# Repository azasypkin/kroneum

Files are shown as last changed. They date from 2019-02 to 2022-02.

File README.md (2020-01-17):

# 🕐 Kroneum



**Disclaimer:** I needed a dumb, autonomous, configurable and GUI-less physical timer to better manage my own time during the day and that is how Kroneum was born. 
Another goal was to see how well Rust fits into embedded development (basic interactions with MCU, USB stack and I2C driver).

------------------------

**Kroneum** is an experimental, accessible (no GUI) and fully open source (both in code and hardware) time tracker device.

There is neither GUI/LCD nor Wi-Fi/Bluetooth interface available, just two buttons one can use to configure the timer. More advanced users can use built-in USB functionality
to configure device (via dedicated [CLI tool](./sw/cli) with optional Web interface), upgrade firmware (via [DFU interface](./sw/firmware/README.md)) or upload various Krouneum "recipes" (e.g. to repurpose device completely).

## Usage

By default device stays in a standby low power mode and wakes up as soon as any of the button is being pressed for 3-5 seconds. As mentioned above there are just two buttons: **Ⅰ** (Roman `one`) and **Ⅹ** (Roman `ten`).

* Long press on **Ⅰ** or **Ⅹ** button when in `StandBy` mode - device enters into `Setup` mode
* Short press on **Ⅰ** when in `Setup` mode - increases desired timer by one `unit`
* Short press on **Ⅹ** when in `Setup` mode - increases desired timer by ten `units`
* Long press on **Ⅰ** when in `Setup` mode - sets timer treating `unit` as a `second` (see example below)
* Long press on **Ⅹ** when in `Setup` mode - sets timer treating `unit` as a `minute` (see example below)
* Long press on both **Ⅰ** *and* **Ⅹ** when in `Setup` mode - sets timer treating `unit` as an `hour` (see example below)
* Long press on **Ⅰ** *or* **Ⅹ** when in `Alarm` mode - resets current alarm if any and enters `Setup` mode
* Long press on both **Ⅰ** *and* **Ⅹ** when in `Alarm` mode - resets current alarm if any and enters `StandBy` mode
* **Very** long press (5 seconds) on both **Ⅰ** *and* **Ⅹ** - enters `Configuration` mode and powers up USB interface

Once timer fires up it will be repeated every 10 seconds (configurable) until it's acknowledged by the long press on both **Ⅰ** *and* **Ⅹ**.

## Examples:

* Long Press on **Ⅰ** + 5 short presses on **Ⅰ** + long press on **Ⅰ** = `5s` timer
* Long Press on **Ⅰ** + 5 short presses on **Ⅰ** + long press on **Ⅹ** = `5m` timer
* Long Press on **Ⅰ** + 5 short presses on **Ⅰ** + long press on both **Ⅰ** *and* **Ⅹ** = `5h` timer
* Long Press on **Ⅰ** + 1 short press on **Ⅰ** + 2 short presses on *Ⅹ** + long press on **Ⅰ** = `21s` timer
* Long Press on **Ⅰ** + 1 short press on **Ⅹ** + long press on **Ⅹ** = `10m` timer
* and so on

## Configuration

Advanced users can configure device via USB with the help of dedicated [CLI tool](./sw/cli), assuming device is in `Configuration` mode and
connected to the host PC via micro USB cable:

```bash
$ cargo run -- info

$ cargo run -- beep -n5

$ cargo run -- alarm get
$ cargo run -- alarm set "5m 15s"

$ cargo run -- flash read 0x1f
$ cargo run -- flash write 0x1f 10
$ cargo run -- flash erase

$ cargo run -- reset

```

It's also possible to use CLI tool as a standalone server with a minimalistic Web interface:

```bash
$ cargo run -- ui
  Running Kroneum Web UI on http://127.0.0.1:8080
``` 

Web server is bound to a local `http://127.0.0.1:8080` address and can be accessed with any modern browser:

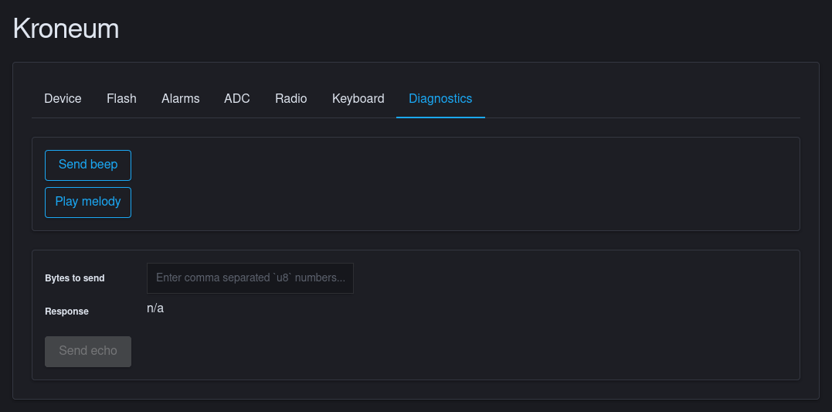
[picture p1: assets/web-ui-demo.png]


Run `cargo run -- help` for more details.

**NOTE:** To use CLI tool without `root` privilege you may need to add the following `udev` rule:
```
/etc/udev/rules.d/50-kroneum.rules
----------
SUBSYSTEMS=="usb", ATTRS{idVendor}=="1209", ATTRS{idProduct}=="deed", GROUP="users", MODE="0660"
```

And then manually force `udev` to trigger this rule:
```bash
# udevadm trigger
```

In the future releases Web interface will be using [WebHID API](https://wicg.github.io/webhid/) completely eliminating the need in
the local Web server.

## Building custom firmware

If you feel adventurous you can easily build and flash custom firmware to Kroneum. You can use `./scripts/flash.sh` script 
from [fw](./sw/firmware) folder to build and flash default firmware or few custom [examples](./sw/firmware/bin/examples):

Default firmware:
```bash
# Default firmware
$ ./scripts/flash.sh 

# Example: blinking through TP1/SDA pad exposed on the back side of Kroneum PCB
$ ./scripts/flash.sh blinky

# Example: interfacing with SSD1306 LCD via TP1/SDA and TP2/SCL pads exposed on the back side of Kroneum PCB
$ ./scripts/flash.sh i2c_ssd1306 
``` 

The `flash.sh` script is essentially consequent calls of `cargo build --release ...`, `cargo objcopy --release ...` and `dfu-util ...`.

## Prototype or DIY

Schematics is done in `KiCad` and can be found [here](./hw/pcb/Rev_0.5). PCB includes SWD, I2C and CR2032 connectors and may look a bit
oversized because of that, but on the bright side hand soldering and [CNC engraving](./hw/pcb/Rev_0.3/cnc) was a breeze.

The most recent enclosure was machined from 5mm (base and cap) and 2mm (buttons) Delrin and the older versions were machined from
5mm Plexiglas (walls and buttons) and 2mm Delrin (base and cap). G-Code can be found [here](./hw/enclosure/Rev_0.5/cnc).

See [PCB](./hw/pcb/Rev_0.6/demo) and [enclosure](./hw/enclosure/Rev_0.6/demo) renders and photos of how it turned in real:

#### Demo PCB and enclosure (rendered vs real)
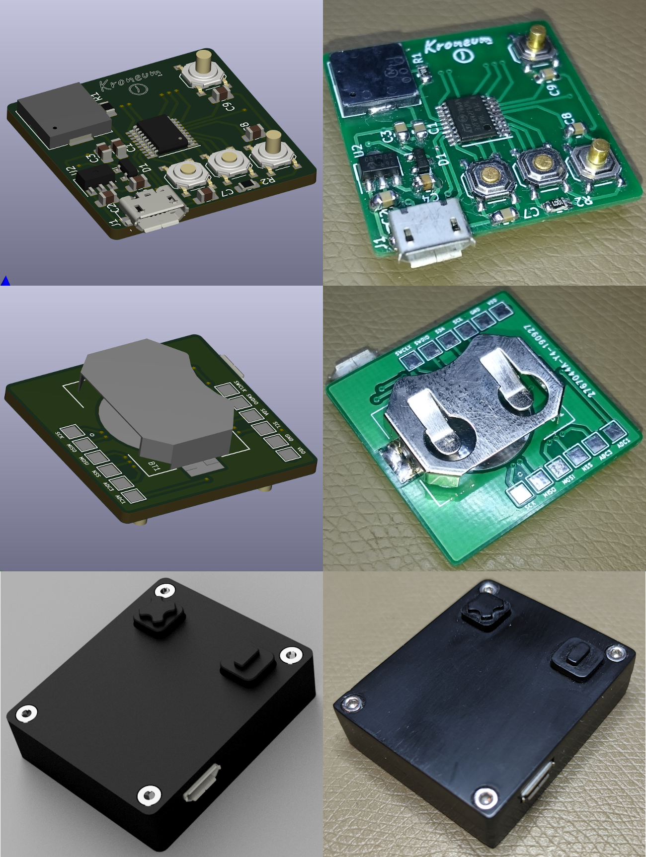
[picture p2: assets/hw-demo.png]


<details>
  <summary><b>Older versions</b></summary>
 
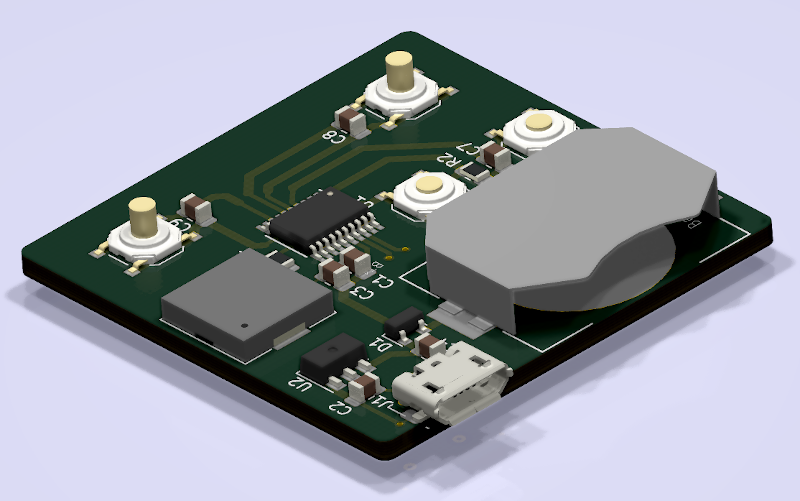
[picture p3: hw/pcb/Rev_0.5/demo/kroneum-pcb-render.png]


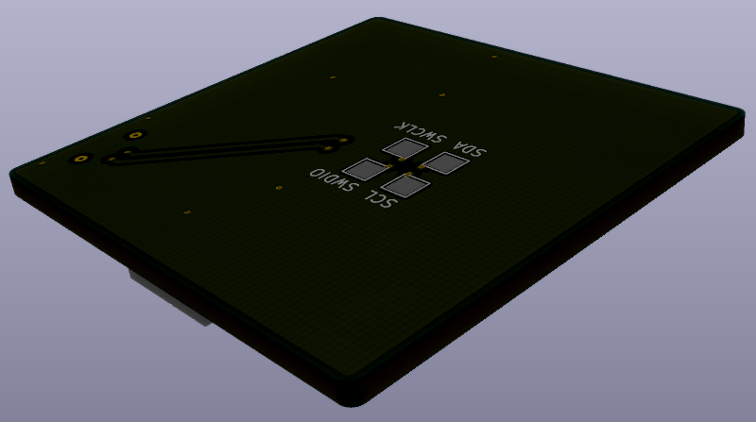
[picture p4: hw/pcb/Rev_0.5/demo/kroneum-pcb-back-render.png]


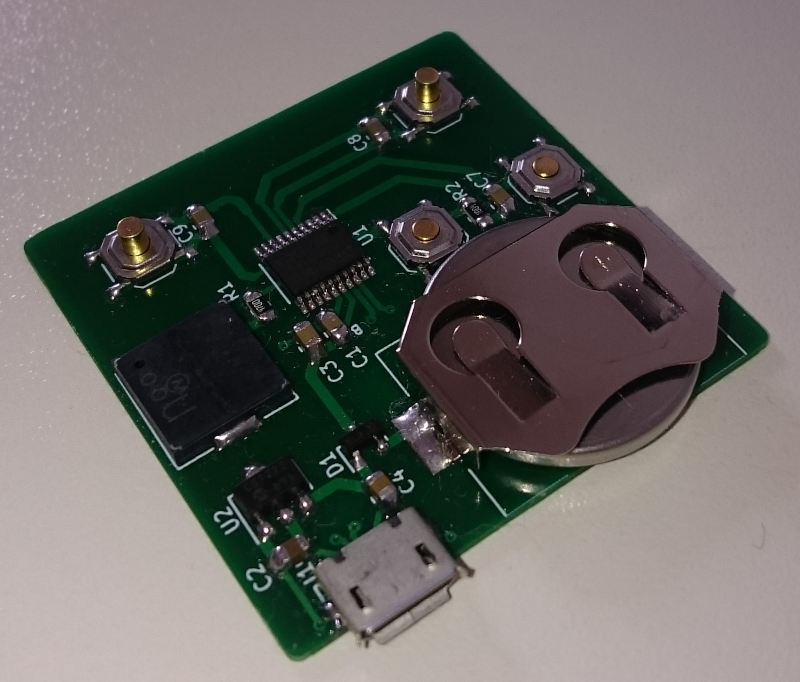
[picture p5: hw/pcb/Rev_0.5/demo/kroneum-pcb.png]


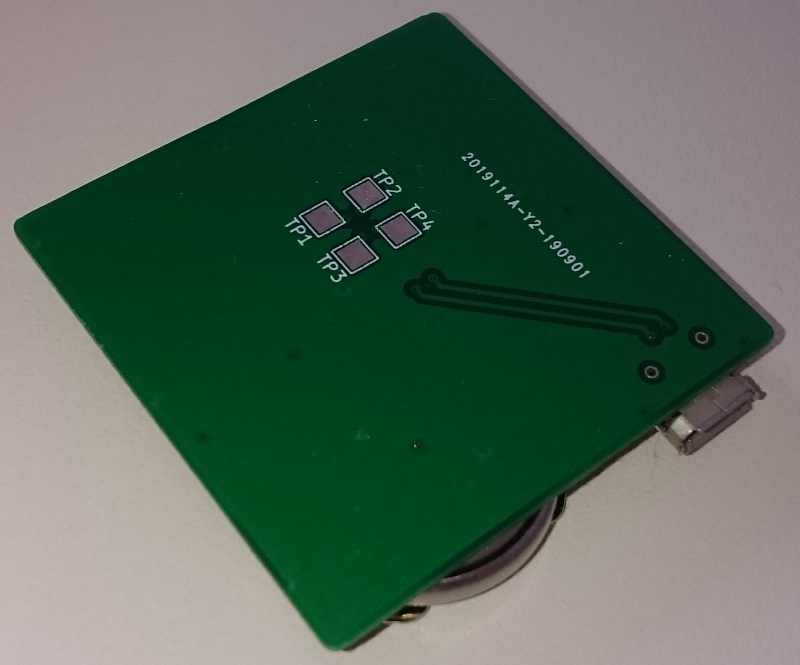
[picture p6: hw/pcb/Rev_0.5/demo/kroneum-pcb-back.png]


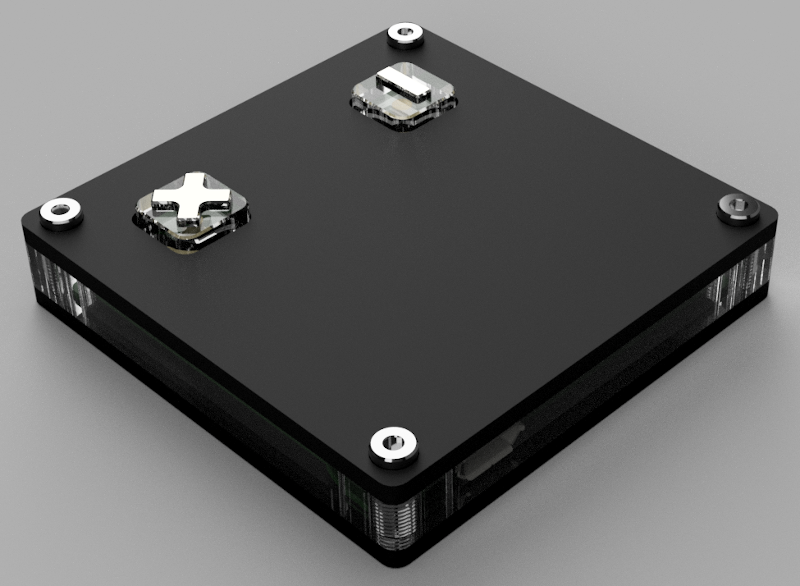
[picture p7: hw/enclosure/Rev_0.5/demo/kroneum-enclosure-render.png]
enclosure


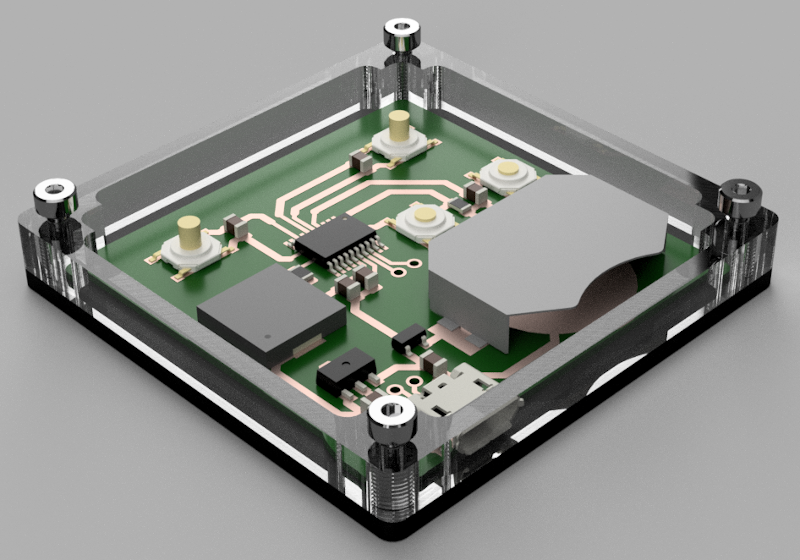
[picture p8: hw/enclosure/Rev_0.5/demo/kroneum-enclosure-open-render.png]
enclosure


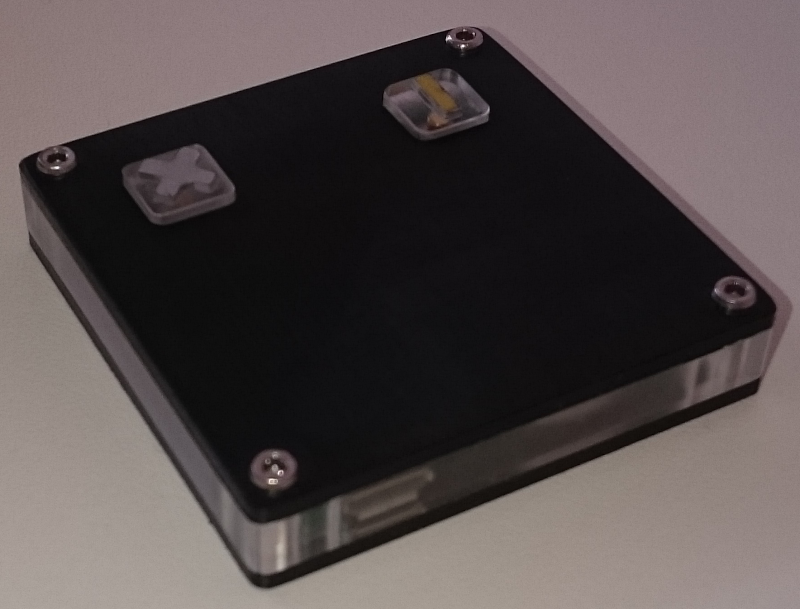
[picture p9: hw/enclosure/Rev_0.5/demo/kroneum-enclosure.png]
enclosure


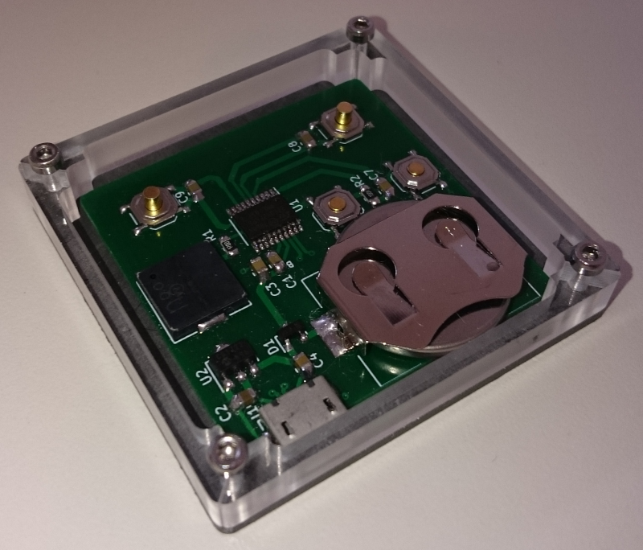
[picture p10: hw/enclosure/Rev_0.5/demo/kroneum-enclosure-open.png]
enclosure


</details>

-.- .-. --- -. . ..- --

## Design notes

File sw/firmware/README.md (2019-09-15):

## Debugging

Firs of all read [The Embedded Rust Book/Hardware](https://rust-embedded.github.io/book/start/hardware.html)!

Will debug with the help of ST-Link included into `STM32F0DISCOVERY` evaluation board. To program and debug `stm32f042f4p6` 
with this board remove the 2 jumpers from CN2 (see [en.DM00050135.pdf](./docs/en.DM00050135.pdf), page 16):

| `STM32F0DISCOVERY` CN3/SWD connector | `STM32F042F4P6` |
| --- | ---:|
| 1 - VDD_TARGET - VDD from target MCU | 16 - VDD __and__ 5 - VDDA |
| 2 - SWCLK - SWD clock | 20 - PA14 |
| 3 - GND - Ground | 15 - GND |
| 4 - SWDIO - SWD data input/output | 19 - PA13 |
| 5 - NRST - RESET of target MCU | 4 - NRST |
| 6 - SWO - Reserved | NC |

1. Add `udev` rule for the `STMicroelectronics ST-LINK/V2`:

```bash
$ sudo vim /etc/udev/rules.d/99-stlink.rules

-------
ATTRS{idVendor}=="0483", ATTRS{idProduct}=="3748", MODE="0666"
-------

$ sudo udevadm trigger
```

1. Build project with one of the following commands:
```bash
$ cargo build
$ cargo build --target=thumbv6m-none-eabi
$ cargo build --target=thumbv6m-none-eabi --release
$ cargo +nightly build --target=thumbv6m-none-eabi --release --features nightly
```
2. Run `openocd -f openocd.cfg`
3. In another terminal run `arm-none-eabi-gdb  -x openocd.gdb target/thumbv6m-none-eabi/release/kroneum-bin`

# Firmware Upload via USB DFU

| `Micro USB` | `STM32F042F4P6`        |
| ------------------------------------:|
| 1 - VBUS +  | NC                     |
| 2 - DATA -  | 09 - PA11 - USB DM     |
| 3 - DATA +  | 10 - PA12 - USB DP     |
| 4 - ID      | NC                     |
| 5 - GND     | 15 - GND               |

Pin 1 (PB8-BOOT0) should be connected to VDD\VDDA (+3.3V).

Also make sure you read documentation for [cargo-binutils](https://github.com/rust-embedded/cargo-binutils) and [dfu-util](http://dfu-util.sourceforge.net/dfuse.html).

1. Build binary with:
```bash
$ cargo build --release -p kroneum-bin
$ $(find $(rustc --print sysroot) -name llvm-objcopy) ./target/thumbv6m-none-eabi/release/kroneum-bin -O binary ./target/fw-upload.bin
Or call the following command from the `./bin` subfolder
$ cargo objcopy --bin kroneum-bin --release -- -O binary ../target/fw-upload.bin
```

2. Upload binary with:
```bash
$ dfu-util -a 0 -d 0483:df11 -s 0x08000000:leave -D ./target/fw-upload.bin
```

3. Backup binary with:
```bash
$ dfu-util -U fw-from-device.bin -a 0 -d 0483:df11
``` 

## Notes

1. Steps 1-3 above can be replaced with just `$ ./scripts/flash.sh`.

2. If binary is too large GDB may fail so try to use `--release` flag with `cargo build`.

3. To reload program on the MCU use `monitor reset halt`

4. RTC & Low Power modes: https://github.com/mattico/stm32f0-Discovery_Tools/blob/master/ST_Example_Projects/Projects/Peripheral_Examples/PWR_CurrentConsumption/stm32f0xx_lp_modes.c

## Useful links

1. [The Embedded Rust Book](https://rust-embedded.github.io/book)
2. [Firmware for Anne Pro Keyboard written in Rust](https://github.com/ah-/anne-key)
3. [USB HID device development on STM32 F042](http://andybrown.me.uk/2016/01/09/f042usbhid/)
4. [A development board for the STM32F042 TSSOP package](http://andybrown.me.uk/2015/10/31/stm32f042dev/) and [schematics](http://andybrown.me.uk/wp-content/images/stm32f042dev/schematic.pdf)
5. [STM32F042 Breakout](http://ebrombaugh.studionebula.com/embedded/stm32f042breakout/index.html)
6. [Tim's Open Micro USB](https://github.com/im-tomu)
7. [Online Circuit Simulator](http://www.falstad.com/circuit/circuitjs.html?startCircuit=lrc.txt)
8. [ifUSB repo](https://github.com/julbouln/ifusb) and [USB multi protocol interface tool](https://hackaday.io/project/14864-ifusb)

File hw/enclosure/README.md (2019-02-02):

## Ideas

* Magnets in enclosure base and cap
* Inserts + screws like https://www.aliexpress.com/item/Uxcell-20pcs-M6-Threaded-Insert-Nuts-Interface-Hex-Socket-Wooden-Furniture-Accessories-Screws-Carbon-Steel-6/32922841586.html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,searchweb201602_4_10320_10065_10068_10547_319_10548_317_10696_453_10084_454_10083_433_10618_431_10304_10307_10820_10821_537_10302_536_5736111_5736011_10843_10059_10884_10887_100031_10319_321_322_10103,searchweb201603_59,ppcSwitch_0&algo_expid=8dacf359-6220-46c2-94f5-eb0ac2e569ab-5&algo_pvid=8dacf359-6220-46c2-94f5-eb0ac2e569ab&transAbTest=ae803_4
* Tight fit https://www.thingiverse.com/thing:1625233

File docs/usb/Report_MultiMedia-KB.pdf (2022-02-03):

## Enhanced Keyboard with Multimedia capability and Application Launch Function

Raj Parihar

Introduction

This application note explains the implementation of Universal Serial Bus (USB) keyboard with enhanced features using microchip‘s USB firmware. Firmware incorporates QWERTY keyboard, multimedia volume control, system power management functionalities along with Application Launch (AL) functions. Design has been implemented using Human Interface Device (HID) class in a composite USB device manner with consumer control application.

Features

- Simple keyboard with Alpha-Numeric keys
- Power management function support i.e. System Wake UP, SLEEP etc.
- Multimedia functionalities with Volume control
- Application Launch capability
- Compatible with Windows and Linux operating system
- No Custom Driver Required, uses generic drivers
- Firmware is portable across all PIC with USB part

USB Protocol: Overview

USB is a simple, reliable, and versatile interface. It is a cost effective and fast means of communication between devices and Host with many other advantages. Universal Bus connectors and 4-wire simple connection makes it a suitable interface for compact devices as well. The bus allows peripherals to be attached, configured, used and detached while the host and other peripherals are in operation.

Application Space in USB

According to USB 2.0 specification

Specification | Bit Rate | Typical Application
LOW - SPEED | 1.5 Mbps | Interactive Devices i.e. Keyboard, Mouse, joysticks etc.
FULL - SPEED | 12 Mbps | Phone, Audio i.e. Broadband, Microphone etc.
HIGH - SPEED | 480 Mbps | Video, Storage i.e. Video application, Imaging etc.

USB Device Terminology

USB device is a collection of end points which can be addressed from USB host controller uniquely. According to USB 2.0 specification Endpoint is ―a uniquely addressable portion of USB device that is the source or sink of information in a communication flow between the host and device‖. The unique address required for each endpoint consists of an endpoint number (which may range from 0 to 15) and direction (IN or OUT). The endpoint direction is always from the host‘s perspective; IN is towards the host and OUT is away from the host. An endpoint configured to do control transfers must transfer data in both directions, so a control endpoint actually consists of a pair of IN and OUT endpoints that share an endpoint number. All USB devices must have Endpoint 0 configured as a control endpoint.

USB Data Transfer Type

USB 2.0 supports four types of data transfers: Control, Bulk, Interrupt and Isochronous.
- Control transfer is used to configure a device at the time of plug-in and can be used for other device specific purposes, including control of other pipes on the device.
- Bulk data transfers are used when the data is generated or consumed in relatively large, bulky quantities.
- Interrupt data transfers are used for timely, and reliable, delivery of data. For example, characters or coordinates with human perceptible echo or feedback response characteristics.
- Isochronous data transfers occupy a pre-negotiated amount of USB bandwidth with pre-negotiated delivery latency (also called streaming real-time transfers).

Human Interface Device Class

The human interface device (HID) class was one of the first USB classes to be supported under Windows and other operating Systems. On PCs running Windows, applications can communicate with HID using the generic HID drivers built into the operating system such as kbdhid.sys and mouhid.sys.

The HID class consists of devices that are used by humans to control the operation of computer systems. Typical examples of HID class devices include:
- Keyboards and pointing devices—for example, standard mouse devices, trackballs, and joysticks.
- Front-panel controls—for example: knobs, switches, buttons, and sliders.
- Controls that might be found on devices such as telephones, VCR remote controls, games or simulation devices—for example: data gloves, throttles, steering wheels, and rudder pedals.

Microchip’s USB Solution

Microchip USB Firmware Framework can be used to create new USB applications. It can be thought of as a reference design project, containing the necessary firmware for USB operation and provides a placeholder for the user‘s code.

The USB Firmware Framework also provides a set of modular firmware interfaces that handle most of the work for implementing USB communications. Each firmware reference project is written to have a cooperative multitasking environment; thus, no blocking functions should be implemented in user code. The files are tightly interdependent, and pass information between themselves during compile time to create the complete USB configuration.

The PIC18 with USB peripheral device families contains a full-speed and low-speed compatible USB Serial Interface Engine (SIE) that allows fast communication between any USB host and PIC microcontroller. The SIE can be interfaced directly to the USB, utilizing the internal transceiver.

For complete information of functions and stack please refer PICDEM FS USB demo board‘s user guide and PIC18 Data sheet available on Microchip‘s website.

Overview: Design

For demonstration purpose a 4 by 4 keypad has been interfaced in current version. Any other type of keyboard with different numbers of rows and columns can be interfaced by writing the appropriate scanning routines for the same. The keypad works in two different modes as following.

Normal Mode:
In normal mode keypad works as simple keyboard. It sends alpha-numeric keys to host whenever a key is pressed. Pressing ‗F‘ (Select) sends the keypad in ―Multimedia Mode‖. Again pressing ‗F‘ brings keypad back in normal mode.

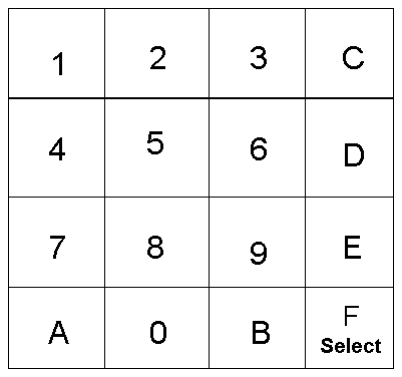
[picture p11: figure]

Figure: Alpha-Numeric Keyboard

Multi Media Mode:
In this mode keypad supports following types of tasks:
1. Volume Control (UP, DOWN and MUTE): [first 3 keys]
2. System Control (System SLEEP and WAKE UP): [ 2 keys towards RHS ]
3. AL function (Media player, Calculator, Browser, Email ): [3 keys in 3rd row
and 1st in 2nd row]
4. Browser Control (Forward, Backward, Refresh): [3 keys in last row]
5. launch ‗Search‘ and ‗Favorite‘: [ 2 keys in 2nd row]

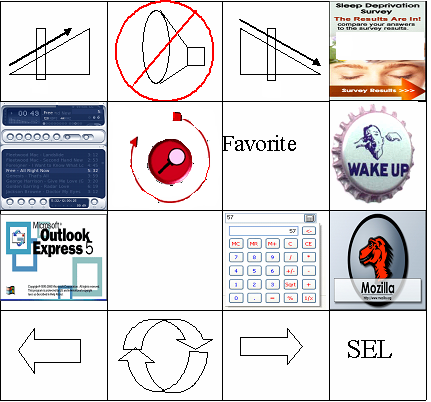
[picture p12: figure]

Figure: Multimedia functions

Implementation

In this implementation of USB/HID keyboards with enhanced features the following design guidelines have been followed.

1. Two HID interfaces has been implemented in a USB composite device fashion, where one interface is used for a standard QWERTY keyboard report that's identical to the keyboard boot protocol report, and the other interface is used for the new, enhanced functionality.
2. Second interface is a consumer control HID usage that implements Volume Up, Volume Down, Mute, and WWW Home buttons using Report ID 1.
3. Keyboard is equipped with Power Management buttons (Sleep, Wake-up, or Power Down buttons), which is implemented in Report ID 2 of second interface.

Interfaces and Endpoint Diagram

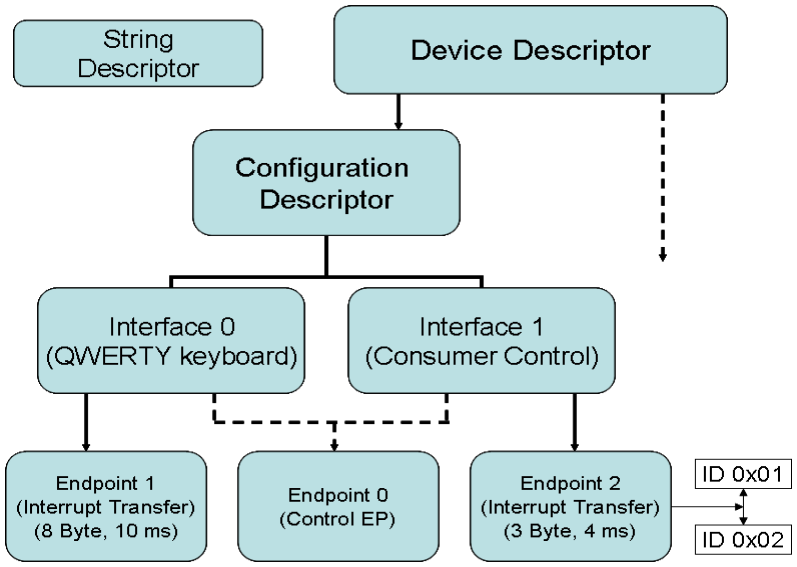
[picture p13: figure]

Figure: Available Endpoints and Interfaces in device

USB Descriptors

### 1. Device Descriptor:

Device descriptor is very first data structure which includes information such as what USB revision the device complies with, the Product and Vendor IDs used to load the appropriate drivers and the number of possible configurations the device can have

/* Device Descriptor */
rom USB_DEV_DSC device_dsc=
{
Sizeof (USB_DEV_DSC), | // Size of this descriptor in bytes: 18
DSC_DEV, | // DEVICE descriptor type: 01
0x0200, | // USB Spec Release Number in BCD format
0x00, | // Class Code; Defined in Interface DSC
0x00, | // Subclass code
0x00, | // Protocol code
EP0_BUFF_SIZE, | // Max packet size for EP0: 0x08
0x04D8, | // Vendor ID: Microchip
0x0111, | // Product ID: for this product
0x0001, | // Device release number in BCD format
0x01, | // Manufacturer string index
0x02, | // Product string index
0x00, | // Device serial number string index
0x01 | // Number of possible configurations
};

### 2. Configuration Descriptor:

Configuration descriptor specifies enabled configuration incase the device has more than one configurations available. Amount of power this particular configuration uses, if the device is self or bus powered and the number of interfaces it has.

A typical configuration descriptor consists of at least one configuration descriptor, one or more interface descriptors and one or more endpoint descriptors.

Here is an example of configuration descriptor‘s definition with two interfaces for enhanced keyboard implementation

#define CFG01 rom struct | \

{ | USB_CFG_DSC | cd01; | \
| USB_INTF_DSC | i00a00; | \
| USB_HID_DSC | hid_i00a00; | \
| USB_EP_DSC | ep01i_i00a00; | \
| USB_INTF_DSC | i01a00; | \
| USB_HID_DSC | hid_i01a00; | \
| USB_EP_DSC | ep02i_i01a00; | \
} cfg01

The current implementation of configuration descriptor is as following.

/* Configuration Descriptor */
Sizeof (USB_CFG_DSC), | // Size of this descriptor in bytes: 09
DSC_CFG, | // CONFIGURATION descriptor type: 02
Sizeof (cfg01), | // Total length of data for this cfg
2, | // Number of interfaces in this cfg: 02
1, | // Index value of this configuration
0, | // Configuration string index
_DEFAULT|_RWU, | // Attributes, see usbdefs_std_dsc.h
50, | // Max power consumption (2X mA): 100 mA

### 3. Interface Descriptor:

A configuration's interface descriptor contains information about the endpoints the interface supports. Each configuration must support at least one interface. In the current implementation two interfaces has been implemented in following manner.

Keyboard functionality is supported by interface 1.

/* Interface 1 Descriptor: QWERTY Keyboard Function */
sizeof(USB_INTF_DSC), | // Size of this descriptor in bytes: 09
DSC_INTF, | // INTERFACE descriptor type: 02
0, | // Interface Number
0, | // Alternate Setting Number
1, | // Number of endpoints in this interface
HID_INTF, | // Class code: 0x03
BOOT_INTF_SUBCLASS, | // Subclass code: 0x01
HID_PROTOCOL_KEYBOAD, | // Protocol code: 0x01
0, | // Interface string index

Multimedia and AL function are supported by interface 2, which supports two report formats.

/* Interface 2 Descriptor: Multimedia and AL support */
sizeof(USB_INTF_DSC), | // Size of this descriptor in bytes: 09
DSC_INTF, | // INTERFACE descriptor type: 02
1, | // Interface Number
0, | // Alternate Setting Number
1, | // Number of endpoints in this interface
HID_INTF, | // Class code: 0x03
NO_INTF_SUBCLASS, | // Subclass code should come here, if any
HID_PROTOCOL_NONE, | // Protocol code should come here, if any
1, | // Interface string index

### 4. Class Specific Descriptor:

A class specific descriptor tells host about the current USB class specs version, country code, size of input and output report which would be used during the data transfer from device to host or vice versa. The descriptor below implements HID class.

/* HID Class-Specific Descriptor */
sizeof(USB_HID_DSC), | // Size of this descriptor in bytes
DSC_HID, | // HID descriptor type
0x0101, | // HID Spec Release Number in BCD format
0x00, | // Country Code (0x00 for Not supported)
HID_NUM_OF_DSC, | // Number of class descriptors,
DSC_RPT, | // Report descriptor type
sizeof(hid_rpt01), | // Size of the report 1 descriptor
sizeof(hid_rpt02), | // Size of the report 2 descriptor

### 5. End point Descriptor:

The endpoint descriptor identifies the transfer type and direction, as well as some other specifics for the endpoint. There may be many endpoints in a device and endpoints may be shared in different configurations.

Keyboard endpoint uses interrupt transfer mechanism to transfer the data from device to host. Direction of this endpoint is IN and size is 8 Bytes. The descriptor also specifies the time interval which is used by host to poll the endpoint. In this case the polling interval is 10 ms.

/* Endpoint 1 Descriptor: QWERTY Function Endpoint */

sizeof(USB_EP_DSC),DSC_EP,_EP01_IN,_INT,HID_INT_IN_EP01_SIZE,0x0A,

Multimedia function endpoint also uses interrupt transfer mechanism to transfer the data from device to host. Direction of this endpoint is IN and size is 3 Bytes. The descriptor also specifies the time interval which is used by host to poll the endpoint. In this case the polling interval is 4 ms.

/* Endpoint 2 Descriptor: Multimedia Function Endpoint */

sizeof(USB_EP_DSC),DSC_EP,_EP02_IN,_INT,HID_INT_IN_EP02_SIZE,0x04,

Sample Report Descriptors for USB HID keyboard

First HID Interface Report Descriptor (keyboard report identical to the boot protocol):

rom struct{byte report[HID_RPT01_SIZE];}hid_rpt01={
0x05, 0x01, | /* Usage Page (Generic Desktop) | */
0x09, 0x06, | /* Usage (Keyboard) | */
0xA1, 0x01, | /* Collection (Application) | */
0x05, 0x07, | /* | Usage page (Key Codes) | */
0x19, 0xE0, | /* | Usage minimum (224) | */
0x29, 0xE7, | /* | Usage maximum (231) | */
0x15, 0x00, | /* | Logical minimum (0) | */
0x25, 0x01, | /* | Logical maximum (1) | */
0x75, 0x01, | /* | Report size (1) | */
0x95, 0x08, | /* | Report count (8) | */
0x81, 0x02, | /* | Input (data, variable, absolute) | */
0x95, 0x01, | /* | Report count (1) | */
0x75, 0x08, | /* | Report size (8) | */
0x81, 0x01, | /* | Input (constant) | */
0x95, 0x06, | /* | Report count (6) | */
0x75, 0x08, | /* | Report size (8) | */
0x15, 0x00, | /* | Logical minimum (0) | */
0x25, 0x65, | /* | Logical maximum (101) | */
0x05, 0x07, | /* | Usage page (key codes) | */
0x19, 0x00, | /* | Usage minimum (0) | */
0x29, 0x65, | /* | Usage maximum (101) | */
0x81, 0x00, | /* | Input (data, array) | */
0xC0}; | /* End Collection | */

The second HID interface will issue one of two possible input reports, each distinguished by a unique Report ID, depending on what control the user is manipulating.

rom struct{byte report[HID_RPT02_SIZE];}hid_rpt02={
0x05, 0x0c, | // USAGE_PAGE (Consumer Devices)
0x09, 0x01, | // USAGE (Consumer Control)
0xa1, 0x01, | // COLLECTION (Application)
0x85, 0x01, | // | REPORT_ID (1)
0x15, 0x00, | // | LOGICAL_MINIMUM (0)
0x25, 0x01, | // | LOGICAL_MAXIMUM (1)
0x75, 0x01, | // | REPORT_SIZE (1)
0x95, 0x10, | // | REPORT_COUNT (16)
0x09, 0xe2, | // | USAGE (Mute) 0x01
0x09, 0xe9, | // | USAGE (Volume Up) 0x02
0x09, 0xea, | // | USAGE (Volume Down) 0x03
0x09, 0xcd, | // | USAGE (Play/Pause) 0x04
0x09, 0xb7, | // | USAGE (Stop) 0x05
0x09, 0xb6, | // | USAGE (Scan Previous Track) 0x06
0x09, 0xb5, | // | USAGE (Scan Next Track) 0x07
0x0a, 0x8a, 0x01, | // | USAGE (Mail) 0x08
0x0a, 0x92, 0x01, | // | USAGE (Calculator) 0x09
0x0a, 0x21, 0x02, | // | USAGE (www search) 0x0a
0x0a, 0x23, 0x02, | // | USAGE (www home) 0x0b
0x0a, 0x2a, 0x02, | // | USAGE (www favorites) 0x0c
0x0a, 0x27, 0x02, | // | USAGE (www refresh) 0x0d

0x0a, 0x26, 0x02, | // | USAGE (www stop) 0x0e
0x0a, 0x25, 0x02, | // | USAGE (www forward) 0x0f
0x0a, 0x24, 0x02, | // | USAGE (www back) 0x10
0x81, 0x62, | // | INPUT (Data,Var,Abs,NPrf,Null)
0xc0,
// System Control Descriptor
0x05, 0x01, | /* Usage Page (Generic Desktop) | */
0x09, 0x80, | /* Usage (System Control) | */
0xA1, 0x01, | /* Collection (Application) | */
0x85, 0x02, | /* Report ID 0x02 [SYSTEM CTRL] | */
0x19, 0x82, | /* | Usage minimum (System Sleep) | */
0x29, 0x83, | /* | Usage maximum (System Wake up) | */
0x95, 0x02, | /* | Report count (2) | */
0x81, 0x06, | /*Input (data, variable, relative, Preferred) | */
0x95, 0x06, | /* | Report count (6) | */
0x81, 0x01, | /*Input (Constant) | */
0xC0 | /*End Collection | */
};

Keyboard Data format

First HID interface will issue 8-byte input reports that are identical to the standard keyboard boot protocol report as documented in the HID Class Version 1.11 specification.

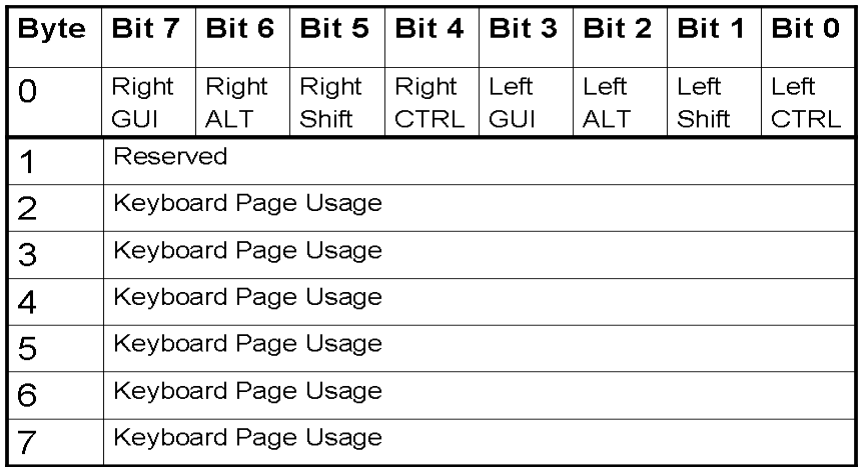
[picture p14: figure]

Second HID interface will issue one of two possible input reports, each distinguished by a unique Report ID, depending on what control the user is manipulating.

Report ID 1

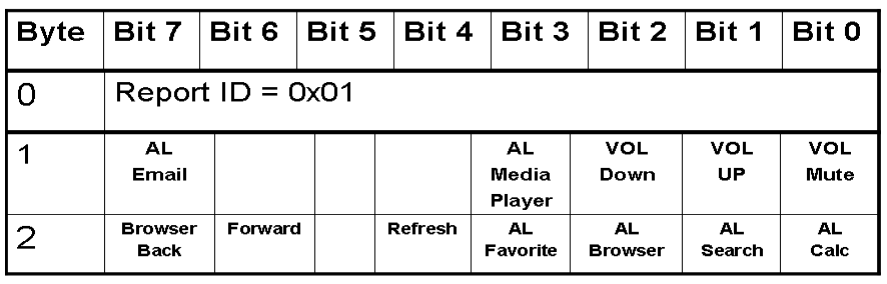
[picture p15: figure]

Report ID 2

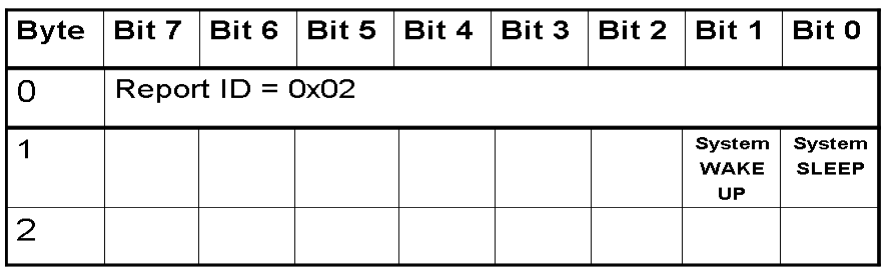
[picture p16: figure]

Firmware Templates

Below is a generic template of main routine. USB driver service and User application should be written in co-operative manner.

Main Routine:
Void main (void)
{
InitializeSystem(); //USB device and user initialization while(1)
{
USBTasks(); | // USB Driver Service Routine
KeypadScan(); | // Keypad scanning routine for key press

/*Load the keyboard buffer with the keyboard HID scan code*/ if(SendFlag == FALSE)
{
if(FunctionFlag == FALSE)
kb_buffer[3] = keyval;
}
else
{
if(FunctionFlag == FALSE)
kb_buffer[3] = 0x00;
}

if(FunctionFlag == FALSE)
Send2Kboard(); //Send as keyboard data else
{
if(ctrl_buffer[0] == ALCtrlID)
Send2ALCtrl(); // send Multimedia and AL data if(ctrl_buffer[0] == SysCtrlID)
Send2SysCtrl(); // send System ctrl data
}

}//end while
}//end main

Routine for alpha-numeric data

void Send2Kboard(void)
{
if(!mHIDTxIsBusy())
{
HIDTxReport(kb_buffer,8);
SendFlag = TRUE;
kb_buffer[3] = 0x00;
}
}

Routine for multimedia function and AL function

void Send2ALCtrl(void)
{
if(!mHIDTx2IsBusy())
{
HIDTx2Report(ctrl_buffer,3); SendFlag = TRUE;
ctrl_buffer[1] = 0x00;
ctrl_buffer[2] = 0x00;
}
}

Routine for system control function

void Send2SysCtrl(void)
{
if(!mHIDTx2IsBusy())
{
HIDTx2Report(ctrl_buffer,2); SendFlag = TRUE;
ctrl_buffer[1] = 0x00;
ctrl_buffer[2] = 0x00;
}
}

Enhanced Keyboard: Firmware Directory structure

The Multimedia Keyboard project source code is broken up into following sub folders under MultimediaKboard as shown below.

Microchip stack application source files in the Root directory MultimediaKboard:

MCHPUSB.mcp | MPLab project file for enhanced keyboard
Main.c | The main file for enhanced keyboard
Io_cfg.h | Contains application specific port configuration information
18f4550.lkr | Linker script for PIC18F4550. Specific to application
autofiles | Subfolder - Microchip USB descriptors and configurations
system | Subfolder - Microchip USB stack chapter 9 specifications
user | Subfolder – User specific routines and interfacing code
Docs | Subfolder – Related documents
_output | Subfolder – compiler output goes here

Microchip USB stack‘s source files in the System Subdirectory:

Hid.c, .h | USB HID communication and interface code
TypeDefs.h | Constants and type definitions used for USB application
usb.h | USB header file
Usb9.c, .h | Performs USB Protocol and command handling
Usb_compile_time_va l.h | USB end point size validation file.
Usbctrltrf.c, .h | USB transfer control handler services
usbdefs_ep0_buff.h | USB end point buffer and structure definition file
usbdefs_std_dsc.h | USB standard descriptor structure file
Usbdrv.c, .h | USB operation handing code and definitions
Usbdsc.c. .h | contains the USB descriptor information and defination
usbmap.c, .h | USB memory manager; compile-time memory allocator for the USB endpoints

Microchip USB stack‘s configurations and descriptors in the autofiles Subdirectory:

usbcfg.h | USB End point configuration file
Usbdsc.c. .h | contains the USB descriptor information and definition

User Specific routines and interfacing code in user subdirectory:

Multimedia_kboard.c,h | Specific routines and interfacing code

Resource Utilization and Future direction:

Here is a summary of resource utilization. The values are approximate for a typical implementation however it can vary depending on application and the way of implementation.

Device Firmware → Resources | USB Multimedia keyboard
Data RAM | 350 Bytes
Program Memory | 4.5 KB
I/O s | Implementation Specific
Power Consumption (Maximum) | < 500 mW

To incorporate additional functionalities one should consider implementation of more interfaces thus more endpoints in order to meat the requirement. If the power drawn by the device is likely to exceed more than 100 mA, self powered option should be used to power up the device instead of Bus powered option.

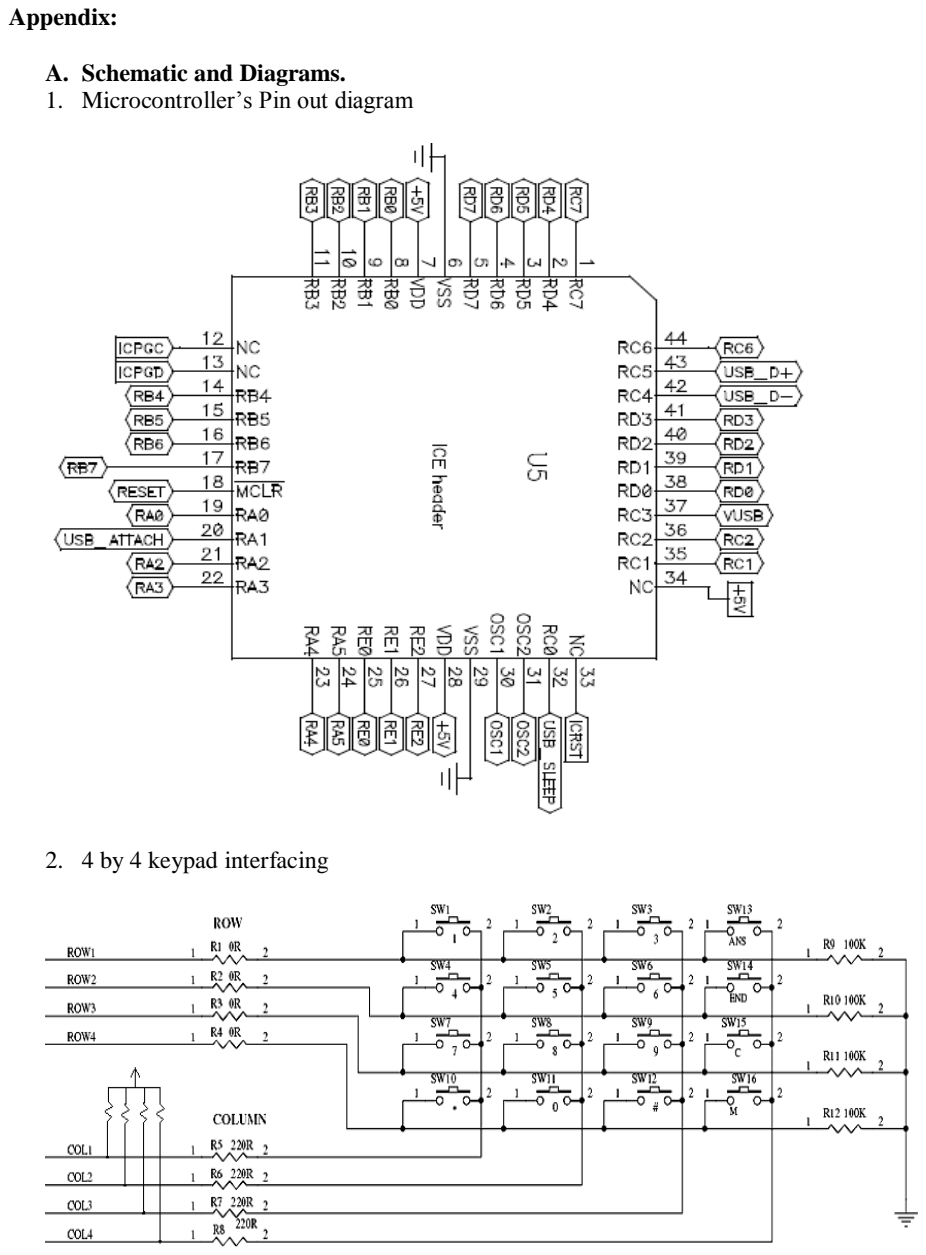
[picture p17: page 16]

Appendix:

A. Schematic and Diagrams.
1. Microcontroller‘s Pin out diagram
2. 4 by 4 keypad interfacing

3. XTAL oscillator (20 MHz)

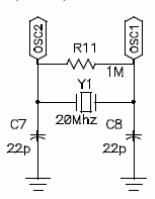
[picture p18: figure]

4. Power Supply Filter (Decoupling capacitor)

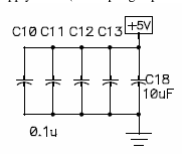
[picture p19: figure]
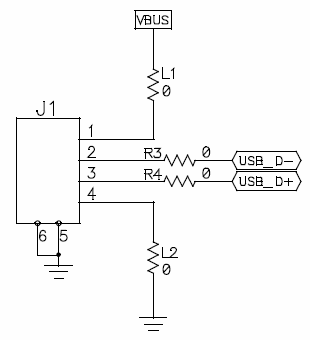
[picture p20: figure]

5. USB Connector

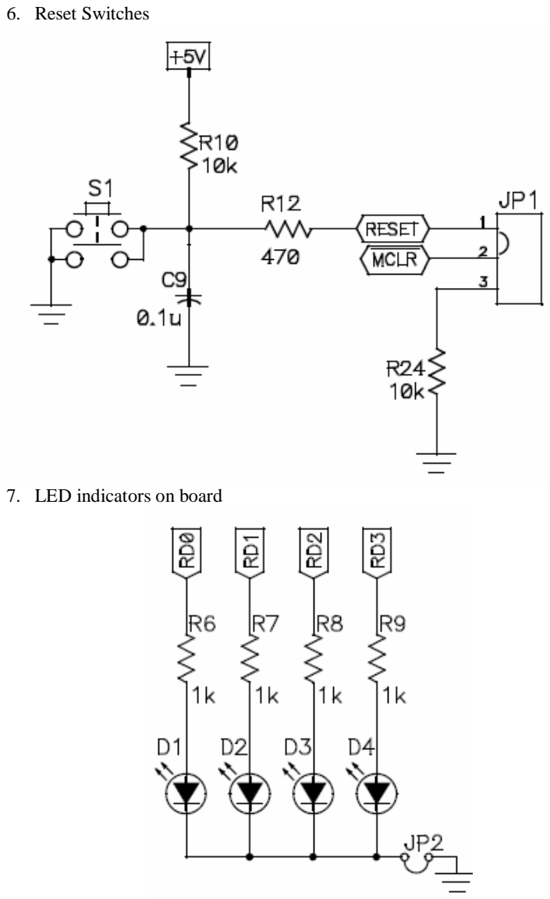
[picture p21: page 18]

6. Reset Switches
7. LED indicators on board

B. Enumeration of Device under Windows OS

Under window when devices gets properly enumerated it gets listed under following sections in device manager.

Under Human Interface Devices (HID):

HID-Compliant Consumer Control Device HID-Compliant device
USB Human Interface Device
USB Human Interface Device

Under Keyboards:

HID Keyboard Device

Under Universal Serial Bus Controllers:

USB Composite Device

Example:

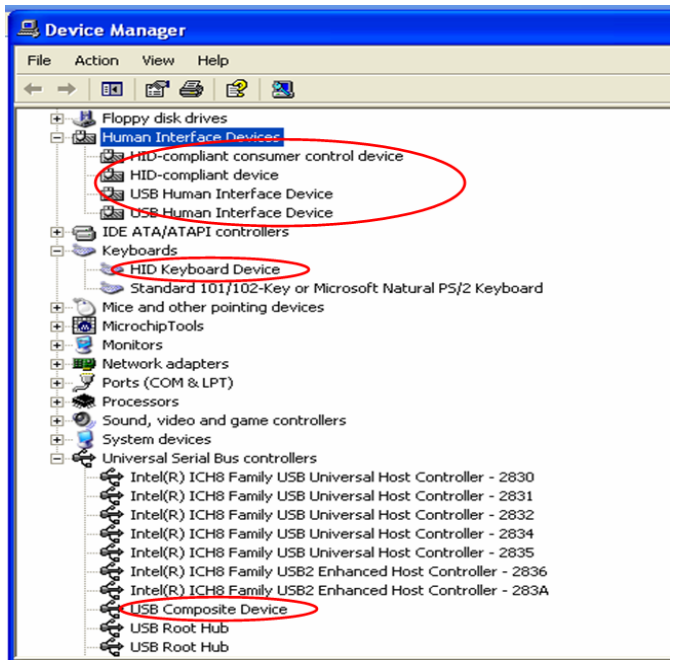
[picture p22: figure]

References

- ―Universal Serial Bus Revision 2.0 Specification‖ http://www.usb.org
- USB Complete: Everything You Need to Develop Custom USB Peripherals by Jan Axelson (http://www.amazon.com/exec/obidos/search-handle-url/104-3691046-8555152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)
- ―USB Device Class Definition for Human Interface Devices (HID) Version 1.11‖ http://www.usb.org
- ‗Microchip Stack for the USB HID Protocol‖ (AN***) http://www.microchip.com/usb
- ―PIC18F2455/2550/4455/4550 full-speed USB 2.0 PIC® microcontrollers Data Sheet‖ (DS39632C)
http://www.microchip.com/datasheet
- ―PICDEM™ FS USB Demonstration Kit User‘s Guide‖ (DS51526A) http://www.microchip.com/picdemfs
- ―Enhanced keyboard and windows‖ from windows hardware development central by Microsoft Inc.
http://www.microsoft.com/whdc/device/input/w2kbd.mspx

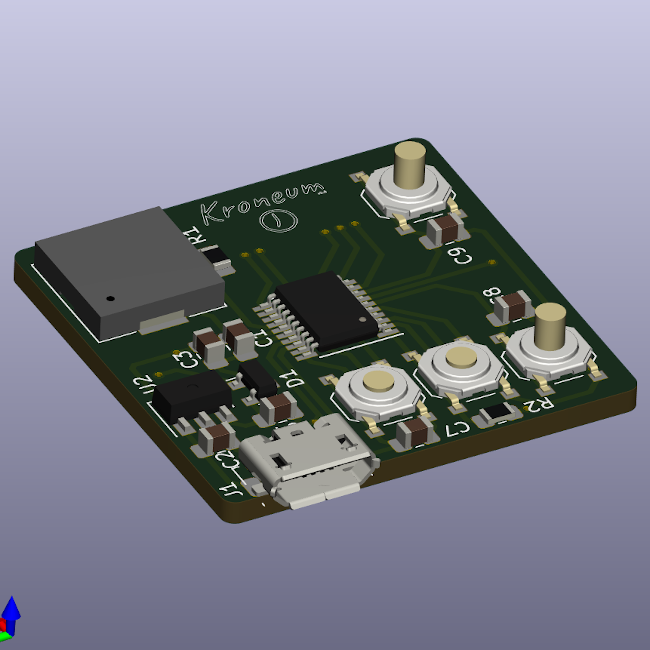
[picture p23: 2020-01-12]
hw/pcb/Rev_0.6/demo/kroneum-pcb-render.png

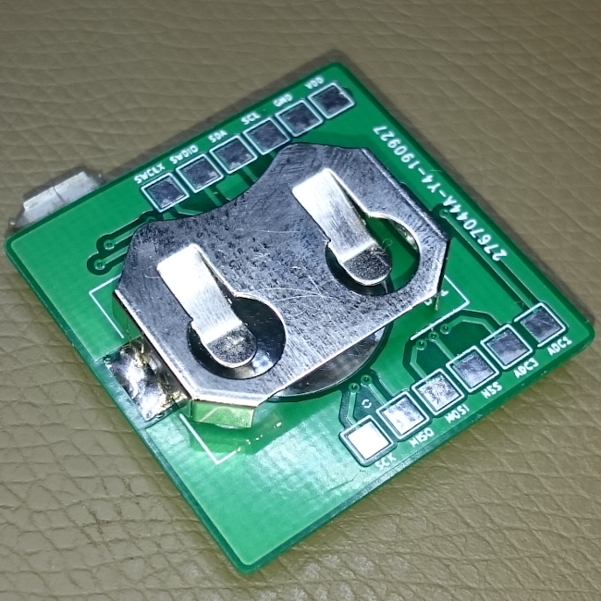
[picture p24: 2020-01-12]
hw/pcb/Rev_0.6/demo/kroneum-pcb-back.png

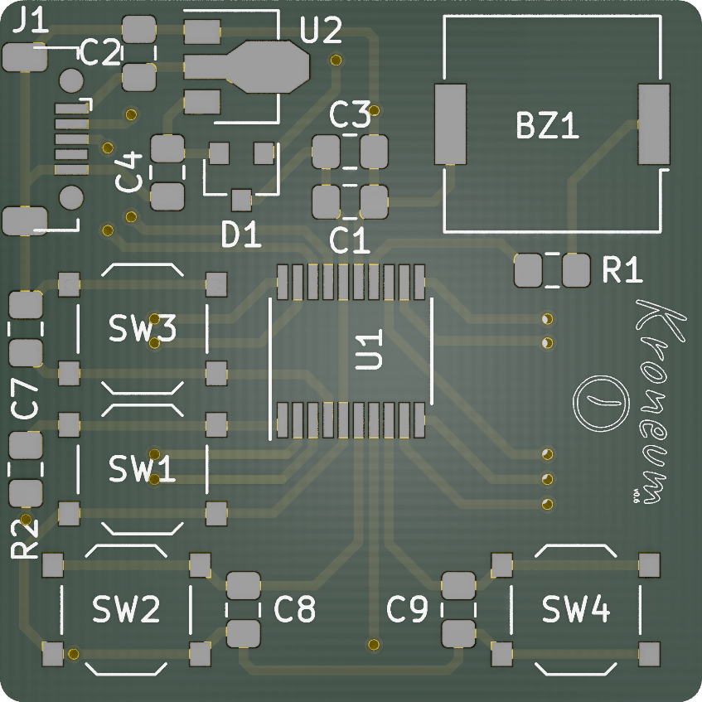
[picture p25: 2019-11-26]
hw/pcb/Rev_0.6/kroneum-traces-top.png

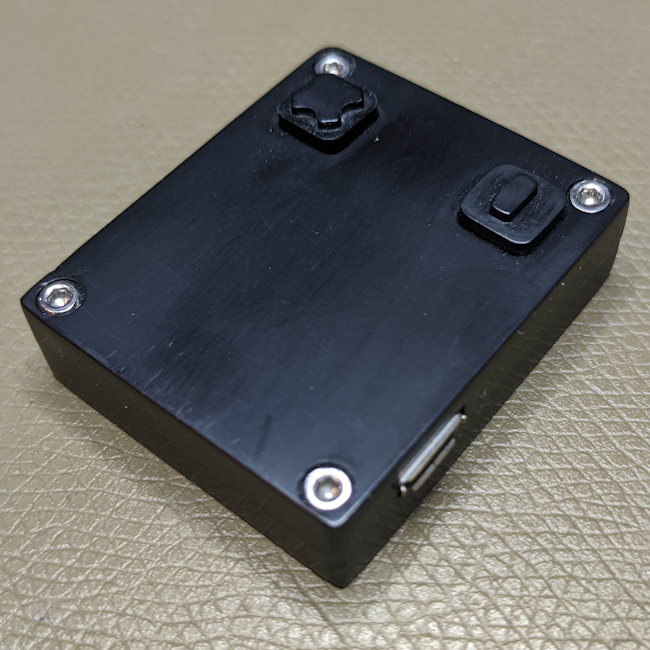
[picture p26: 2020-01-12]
hw/enclosure/Rev_0.6/demo/kroneum-enclosure.png

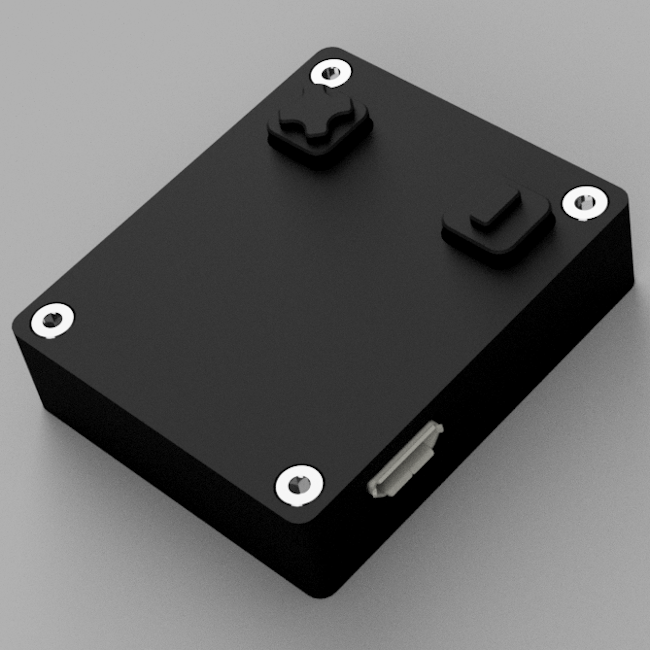
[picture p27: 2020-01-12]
hw/enclosure/Rev_0.6/demo/kroneum-enclosure-render.png

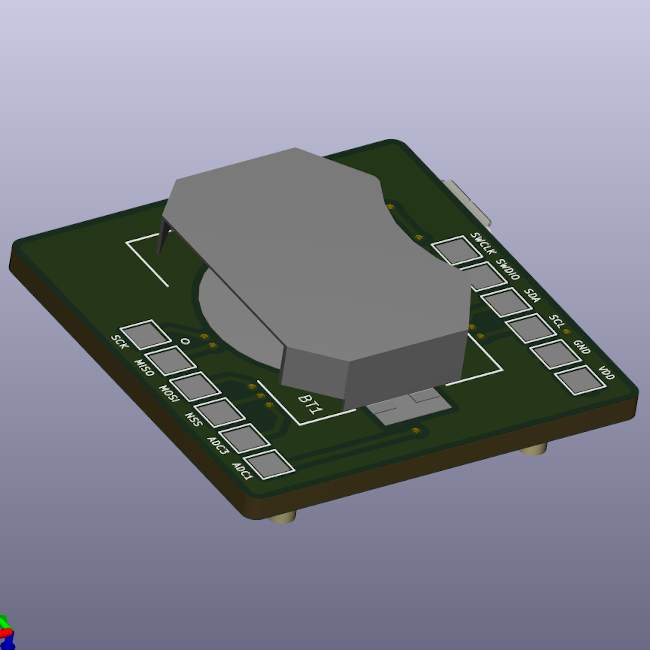
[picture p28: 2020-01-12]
hw/pcb/Rev_0.6/demo/kroneum-pcb-back-render.png

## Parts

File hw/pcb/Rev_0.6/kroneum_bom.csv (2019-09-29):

Qty | Line Item | Manufacturer | MPN | Octopart URL | Schematic Reference | Internal Part Number | Description | Total Qty (@ Batch Size: 1) | SKU | SKU | Packaging | Packaging | Unit Price (@ Batch Size: 1) | Unit Price (@ Batch Size: 1) | In Stock | In Stock | MOQ | MOQ | URL | URL | Distributor [Lowest Price (Overall)] | SKU [Lowest Price (Overall)] | Packaging [Lowest Price (Overall)] | Unit Price (@ Batch Size: 1) [Lowest Price (Overall)] | Line Total [Lowest Price (Overall)] | Batch Total [Lowest Price (Overall)] | In Stock [Lowest Price (Overall)] | MOQ [Lowest Price (Overall)] | URL [Lowest Price (Overall)] | Notes
 |  |  |  |  |  |  |  |  | Digi-Key | Mouser | Digi-Key | Mouser | Digi-Key | Mouser | Digi-Key | Mouser | Digi-Key | Mouser | Digi-Key | Mouser
1 | STM32F042F6P6 | STMicroelectronics | STM32F042F6P6 | https://octopart.com/stm32f042f6p6-stmicroelectronics-34084830 |  |  |  | 1 | 497-17344-ND | 511-STM32F042F6P6 | Tube |  | 2.0566732500000002 | 2.0566732500000002 | 2187 | 6012 | 1 | 1 | https://octopart.com/click/track?ai=8237&sig=0336943&sid=459&ppid=34084830&vpid=438816131&ct=offers | https://octopart.com/click/track?ai=8237&sig=0596617&sid=2401&ppid=34084830&vpid=183946111&ct=offers | LCSC | C81000 |  | 1.2257 | 1.2257 | 1.2257 | 2612 | 1 | https://octopart.com/click/track?ai=8237&sig=0f9f371&sid=27971&ppid=34084830&vpid=445984446&ct=offers
1 | BAT-HLD-001-ND | Linx | BAT-HLD-001 | https://octopart.com/bat-hld-001-linx-12684376 |  |  |  | 1 | BAT-HLD-001-ND | 712-BAT-HLD-001 | Bulk | Bulk | 0.26508233 | 0.26508233 | 28677 | 13225 | 1 | 1 | https://octopart.com/click/track?ai=8237&sig=04b7d6c&sid=459&ppid=12684376&vpid=34288767&ct=offers | https://octopart.com/click/track?ai=8237&sig=0bfad2c&sid=2401&ppid=12684376&vpid=37913373&ct=offers | Digi-Key | BAT-HLD-001-ND | Bulk | 0.26508233 | 0.26508233 | 0.26508233 | 28677 | 1 | https://octopart.com/click/track?ai=8237&sig=04b7d6c&sid=459&ppid=12684376&vpid=34288767&ct=offers
1 | PKMCS0909E4000-R1 | Murata | PKMCS0909E4000-R1 | https://octopart.com/pkmcs0909e4000-r1-murata-33722062 |  |  |  | 1 | 490-9647-1-ND | 81-PKMCS0909E4000-R1 | Cut Tape | Tape & Reel | 1.3711155000000002 | 1.79159092 | 31718 | 7833 | 1 | 1 | https://octopart.com/click/track?ai=8237&sig=0500299&sid=459&ppid=33722062&vpid=123296983&ct=offers | https://octopart.com/click/track?ai=8237&sig=039a195&sid=2401&ppid=33722062&vpid=98198516&ct=offers | Arrow Electronics, Inc. | PKMCS0909E4000-R1 | Cut Tape | 1.2817187693999998 | 1.2817187693999998 | 1.2817187693999998 | 774 | 1 | https://octopart.com/click/track?ai=8237&sig=0b47851&sid=1106&ppid=33722062&vpid=473337975&ct=offers
1 | MCP1700T-3302E/MB | Microchip | MCP1700T-3302E/MB | https://octopart.com/mcp1700t-3302e%2Fmb-microchip-107539 |  |  |  | 1 | MCP1700T3302EMBCT-ND | 579-MCP1700T3302E/MB | Cut Tape | Tape & Reel | 0.34734926 | 0.34734926 | 31850 | 20173 | 1 | 1 | https://octopart.com/click/track?ai=8237&sig=06681aa&sid=459&ppid=107539&vpid=1724555&ct=offers | https://octopart.com/click/track?ai=8237&sig=01b6331&sid=2401&ppid=107539&vpid=37708840&ct=offers | Microchip | MCP1700T-3302E/MB | Tape & Reel | 0.33820849000000003 | 0.33820849000000003 | 0.33820849000000003 | 132262 | 1 | https://octopart.com/click/track?ai=8237&sig=0c12430&sid=13798&ppid=107539&vpid=49600518&ct=offers
1 | BAT54CLT3G | ON Semiconductor | BAT54CLT3G | https://octopart.com/bat54clt3g-on+semiconductor-12177795 |  |  |  | 1 | BAT54CLT3GOSCT-ND | 863-BAT54CLT3G | Cut Tape | Tape & Reel | 0.12797078 | 0.12797078 | 146952 | 93839 | 1 | 1 | https://octopart.com/click/track?ai=8237&sig=0d98475&sid=459&ppid=12177795&vpid=194411454&ct=offers | https://octopart.com/click/track?ai=8237&sig=0ade4c1&sid=2401&ppid=12177795&vpid=37777723&ct=offers | Rochester Electronics | BAT54CLT3G |  | 0.018281540000000002 | 0.018281540000000002 | 0.018281540000000002 | 170000 | 1 | https://octopart.com/click/track?ai=8237&sig=043b270&sid=5832&ppid=12177795&vpid=84979106&ct=offers
1 | 10118192-0001LF | FCI | 10118192-0001LF | https://octopart.com/10118192-0001lf-fci-21265434 |  |  |  | 1 | 609-4613-1-ND | 649-10118192-0001LF | Cut Tape | Tape & Reel | 0.39305311 | 0.40219388 | 69756 | 37512 | 1 | 1 | https://octopart.com/click/track?ai=8237&sig=01a42ab&sid=459&ppid=21265434&vpid=531263943&ct=offers | https://octopart.com/click/track?ai=8237&sig=05fd705&sid=2401&ppid=21265434&vpid=45455345&ct=offers | Freelance Electronics | 10118192-0001LF |  | 0.13332727122 | 0.13332727122 | 0.13332727122 | 370 | 1 | https://octopart.com/click/track?ai=8237&sig=0b169ed&sid=13062&ppid=21265434&vpid=262563965&ct=offers
4 | CL21B104KBCNNNC | Samsung | CL21B104KBCNNNC | https://octopart.com/cl21b104kbcnnnc-samsung-9299352 |  |  |  | 4 | 1276-1003-1-ND |  | Cut Tape |  | 0.09140770000000001 |  | 496650 |  | 1 |  | https://octopart.com/click/track?ai=8237&sig=0e879f3&sid=459&ppid=9299352&vpid=72526069&ct=offers |  | Quest | CL21B104KBCNNNC |  | 0.039762349499999995 | 0.15904939799999998 | 0.15904939799999998 | 83775 | 1 | https://octopart.com/click/track?ai=8237&sig=0c72931&sid=2412&ppid=9299352&vpid=490151156&ct=offers
2 | CL21A105KACLNNC | Samsung | CL21A105KACLNNC | https://octopart.com/cl21a105kaclnnc-samsung-11542315 |  |  |  | 2 | 1276-2395-1-ND |  | Cut Tape |  | 0.12797078 |  | 1635 |  | 1 |  | https://octopart.com/click/track?ai=8237&sig=0c4b900&sid=459&ppid=11542315&vpid=72525687&ct=offers |  | Digi-Key | 1276-2395-1-ND | Cut Tape | 0.12797078 | 0.25594156 | 0.25594156 | 1635 | 1 | https://octopart.com/click/track?ai=8237&sig=0c4b900&sid=459&ppid=11542315&vpid=72525687&ct=offers
1 | CL21A475KPCLNNC | Samsung | CL21A475KPCLNNC | https://octopart.com/cl21a475kpclnnc-samsung-21395695 |  |  |  | 1 | 1276-2417-1-ND |  | Cut Tape |  | 0.16453386 |  | 362140 |  | 1 |  | https://octopart.com/click/track?ai=8237&sig=0fab84d&sid=459&ppid=21395695&vpid=72525898&ct=offers |  | Arrow Electronics, Inc. | CL21A475KPCLNNC | Cut Tape | 0.15630716700000002 | 0.15630716700000002 | 0.15630716700000002 | 11502 | 1 | https://octopart.com/click/track?ai=8237&sig=0f4f54e&sid=1106&ppid=21395695&vpid=473428254&ct=offers
1 | ERJ-6ENF4700V | Panasonic | ERJ-6ENF4700V | https://octopart.com/erj-6enf4700v-panasonic-9251399 |  |  |  | 1 | P470CCT-ND | 667-ERJ-6ENF4700V | Cut Tape | Tape & Reel | 0.09140770000000001 | 0.09140770000000001 | 46084 | 63289 | 1 | 1 | https://octopart.com/click/track?ai=8237&sig=0436e3f&sid=459&ppid=9251399&vpid=115222596&ct=offers | https://octopart.com/click/track?ai=8237&sig=01f1b56&sid=2401&ppid=9251399&vpid=115159331&ct=offers | Quest | ERJ6ENF4700V |  | 0.032906772 | 0.032906772 | 0.032906772 | 14759 | 1 | https://octopart.com/click/track?ai=8237&sig=01b7fa2&sid=2412&ppid=9251399&vpid=195923729&ct=offers
1 | ERJ-6ENF1004V | Panasonic | ERJ-6ENF1004V | https://octopart.com/erj-6enf1004v-panasonic-55403682 |  |  |  | 1 | P1.00MCCT-ND | 667-ERJ-6ENF1004V | Cut Tape | Tape & Reel | 0.09140770000000001 | 0.09140770000000001 | 400134 | 292830 | 1 | 1 | https://octopart.com/click/track?ai=8237&sig=08083ec&sid=459&ppid=55403682&vpid=188062522&ct=offers | https://octopart.com/click/track?ai=8237&sig=09a3424&sid=2401&ppid=55403682&vpid=187840508&ct=offers | Voyager Components | ERJ6ENF1004VPANASONICN/A |  | 0.009140770000000001 | 0.009140770000000001 | 0.009140770000000001 | 8971 | 1 | https://octopart.com/click/track?ai=8237&sig=06b3a5c&sid=2424&ppid=55403682&vpid=562542487&ct=offers
4 | PTS526 SK15 SMTR2 LFS | C&K Components | PTS526 SK15 SMTR2 LFS | https://octopart.com/pts526+sk15+smtr2+lfs-c%26k+components-100617999 |  |  |  | 4 | CKN12221-1-ND | 611-PTS526SK15SMR2L | Cut Tape | Tape & Reel | 0.09140770000000001 | 0.09140770000000001 | 4960 | 0 | 1 | 1 | https://octopart.com/click/track?ai=8237&sig=0ddf7a6&sid=459&ppid=100617999&vpid=536764556&ct=offers | https://octopart.com/click/track?c=1&ai=8237&sig=035fcb3&sid=2401&ppid=100617999&vpid=586605336&ct=offers | Arrow Electronics, Inc. | PTS526 SK15 SMTR2 LFS | Cut Tape | 0.086837315 | 0.34734926 | 0.34734926 | 3946 | 1 | https://octopart.com/click/track?ai=8237&sig=04c9444&sid=1106&ppid=100617999&vpid=560631872&ct=offers

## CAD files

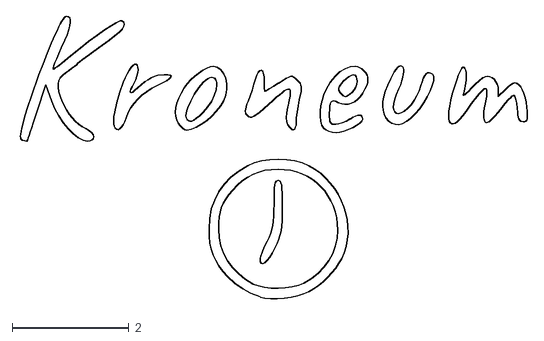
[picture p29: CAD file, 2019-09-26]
hw/pcb/Rev_0.6/kroneum-silkscreen-logo.dxf
8.76 x 4.86

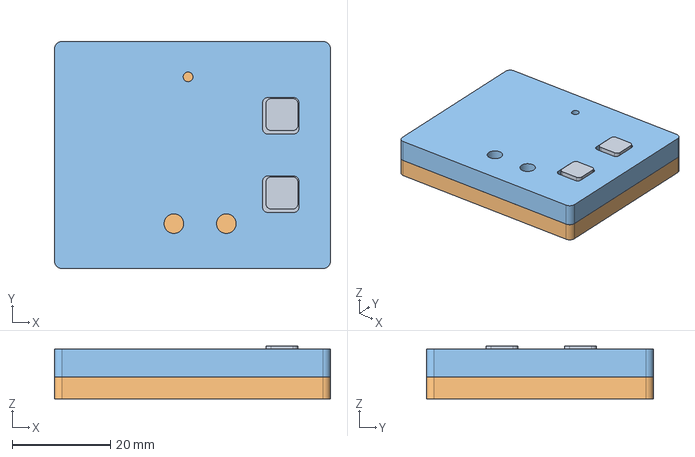
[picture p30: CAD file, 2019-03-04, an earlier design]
hw/enclosure/Rev_0.2/kroneum.step
56.3 x 46.3 x 10.8 mm
Button x 2

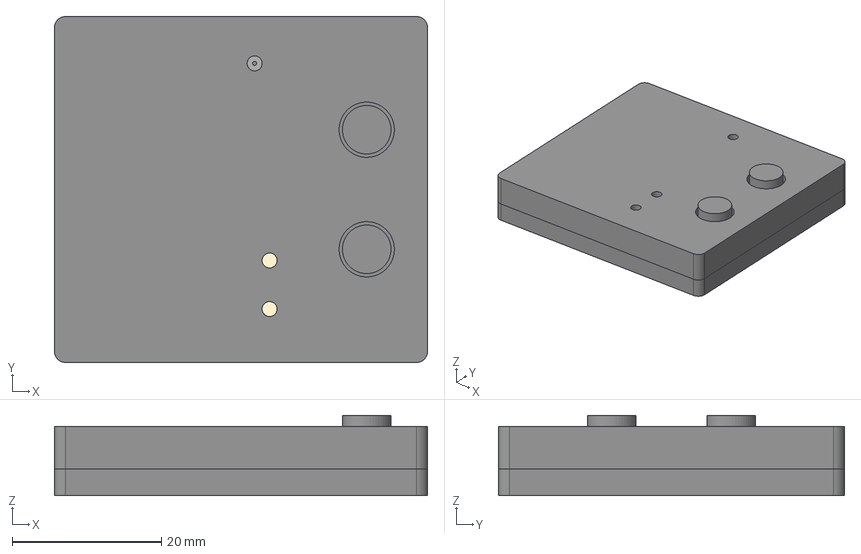
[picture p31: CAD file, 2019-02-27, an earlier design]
hw/enclosure/Rev_0.3/kroneum.step
50.0 x 46.3 x 10.8 mm
Button

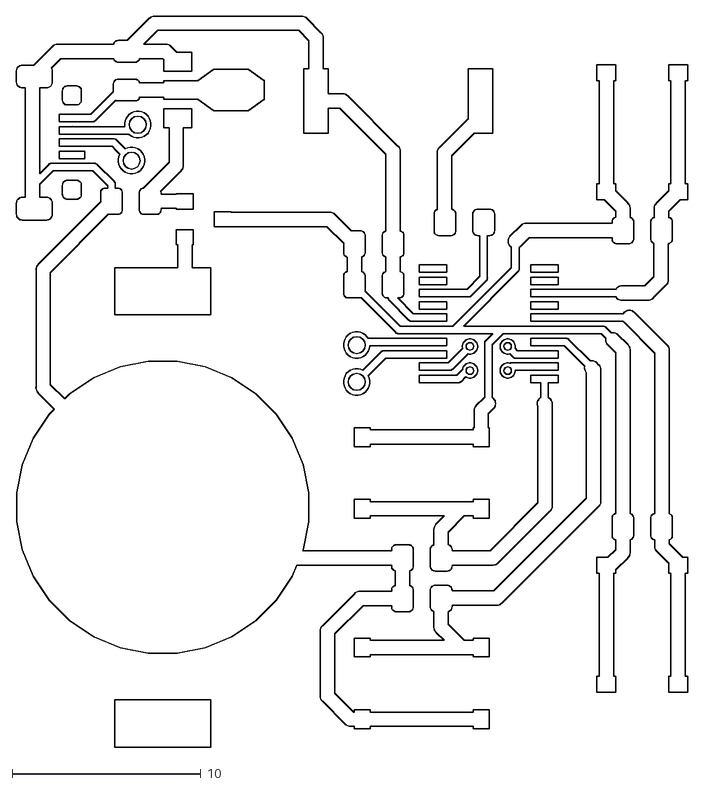
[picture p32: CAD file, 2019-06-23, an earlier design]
hw/pcb/Rev_0.5/cnc/kroneum-F_Cu.dxf
35.6 x 38.7

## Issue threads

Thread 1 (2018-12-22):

[docs] Describe device

azasypkin, 2018-12-22:
Portable battery-powered device with two buttons, one speaker/buzzer and micro USB port.

USB port is used to charge re-chargeable battery, flash firmware over DFU and act as a USB HID device (for sync, buttons mapping, logging, control over CLI etc.).

Speaker/buzzer is used to alarm whenever timer hits zero.

Two buttons are used to control timer:

* **Ⅰ (one)** - short click increases timer time by one unit
* **Ⅹ (ten)** - short click increases timer time by ten units

Long press on **Ⅰ (one)** sets timer using second as a unit.
Long press on **Ⅹ (ten)** sets timer using minute as a unit.
Long press on both **Ⅰ (one)** and **Ⅹ (ten)** simultaneously sets timer using hour as a unit.

Whenever timer is set devices enters sleep/low power mode and relies on RTC to wake up when timer hits zero.

One can reset current timer and enter setup mode just by long pressing both **Ⅰ (one)** and **Ⅹ (ten)** buttons simultaneously.

USB HID mode is activated when device is connected to USB port and both **Ⅰ (one)** and **Ⅹ (ten)** buttons are pressed simultaneously for longer time than usual long press.

Closed 2018-12-22.

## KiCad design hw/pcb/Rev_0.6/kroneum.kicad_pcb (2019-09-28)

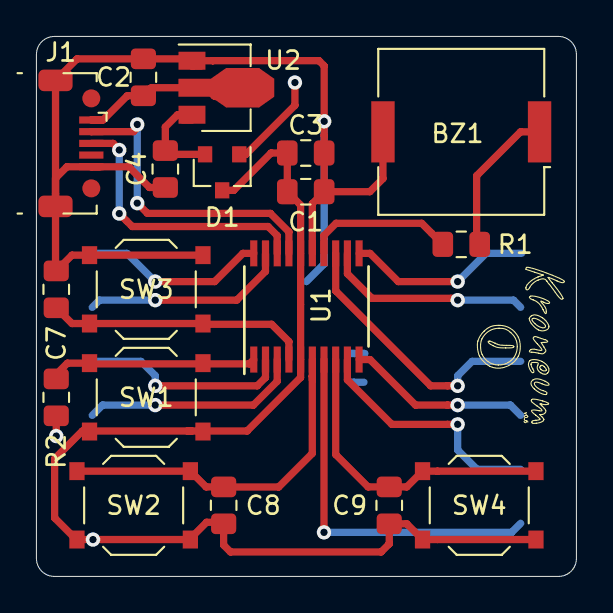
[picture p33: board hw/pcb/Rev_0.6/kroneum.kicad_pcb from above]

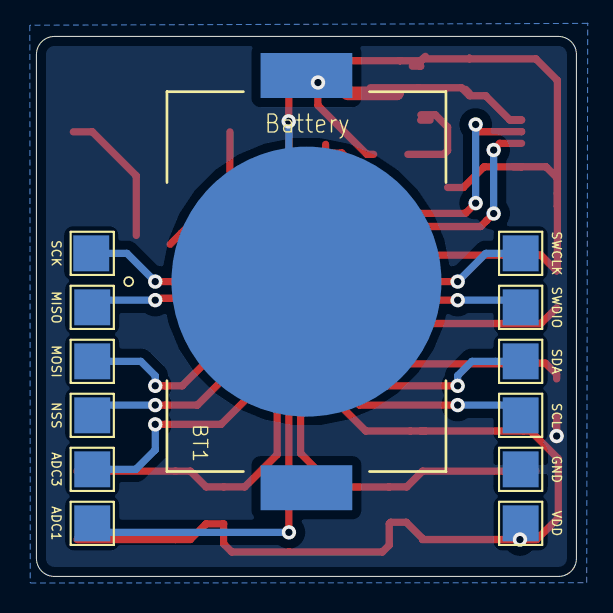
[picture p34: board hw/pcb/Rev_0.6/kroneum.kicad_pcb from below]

Board: 2 copper layers, 30.0 x 30.0 mm, 31 parts (13 on the bottom side), 23 nets.

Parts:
ADC1, ADC3: Peripherals; TestPoint_THTPad_2.0x2.0mm_Drill1.0mm
BT1: Battery; LINX_BAT-HLD-001_0
BZ1: Buzzer; Buzzer_Murata_PKMCS0909E4000-R1
C1, C7, C8, C9: 0.1u; C_0805_2012Metric_Pad1.15x1.40mm_HandSolder
C2, C4: 1u; C_0805_2012Metric_Pad1.15x1.40mm_HandSolder
C3: 4.7u; C_0805_2012Metric_Pad1.15x1.40mm_HandSolder
D1: BAT54C; SOT-23
GND: Peripherals; TestPoint_THTPad_2.0x2.0mm_Drill1.0mm
J1: USB_B_Micro; USB_Micro-B_Molex-105017-0001
MISO: Peripherals; TestPoint_THTPad_2.0x2.0mm_Drill1.0mm
MOSI: Peripherals; TestPoint_THTPad_2.0x2.0mm_Drill1.0mm
NSS: Peripherals; TestPoint_THTPad_2.0x2.0mm_Drill1.0mm
R1: 470; R_0805_2012Metric_Pad1.15x1.40mm_HandSolder
R2: 1M; R_0805_2012Metric_Pad1.15x1.40mm_HandSolder
SCK: Peripherals; TestPoint_THTPad_2.0x2.0mm_Drill1.0mm
SCL: Peripherals; TestPoint_THTPad_2.0x2.0mm_Drill1.0mm
SDA: Peripherals; TestPoint_THTPad_2.0x2.0mm_Drill1.0mm
SW1: Boot_Mode_Btn; tl3342
SW2: Ctrl_One_Btn; tl3342
SW3: Reset_Btn; tl3342
SW4: Ctrl_Ten_Btn; tl3342
SWCLK: Peripherals; TestPoint_THTPad_2.0x2.0mm_Drill1.0mm
SWDIO: Peripherals; TestPoint_THTPad_2.0x2.0mm_Drill1.0mm
U1: STM32F042F4Px; TSSOP-20_4.4x6.5mm_P0.65mm
U2: MCP1700-3302E_SOT89; SOT-89-3
VDD: Peripherals; TestPoint_THTPad_2.0x2.0mm_Drill1.0mm

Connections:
ADC1: ADC1.1, U1.7
ADC3: ADC3.1, U1.9
BOOT0: R2.1, SW1.1, U1.1
Buzzer: R1.2, U1.14
Ctrl_One: C8.2, SW2.1, U1.6
Ctrl_Ten: C9.2, SW4.1, U1.8
GND: BT1.2, BZ1.2, C1.2, C2.1, C3.2, C4.2, C7.2, GND.1, J1.5, J1.6, R2.2, SW3.2, U1.15, U2.1
MISO: MISO.1, U1.12
MOSI: MOSI.1, U1.13
NRST: C7.1, SW3.1, U1.4
NSS: NSS.1, U1.10
unnamed: BT1.1, D1.1
unnamed: BZ1.1, R1.1
unnamed: C4.1, D1.2, U2.3
SCK: SCK.1, U1.11
SCL: SCL.1, U1.3
SDA: SDA.1, U1.2
SWCLK: SWCLK.1, U1.20
SWDIO: SWDIO.1, U1.19
USB_D+: J1.3, U1.18
USB_D-: J1.2, U1.17
USB_VBUS: C2.2, J1.1, U2.2
VDD: C1.1, C3.1, C8.1, C9.1, D1.3, SW1.2, SW2.2, SW4.2, U1.5, U1.16, VDD.1

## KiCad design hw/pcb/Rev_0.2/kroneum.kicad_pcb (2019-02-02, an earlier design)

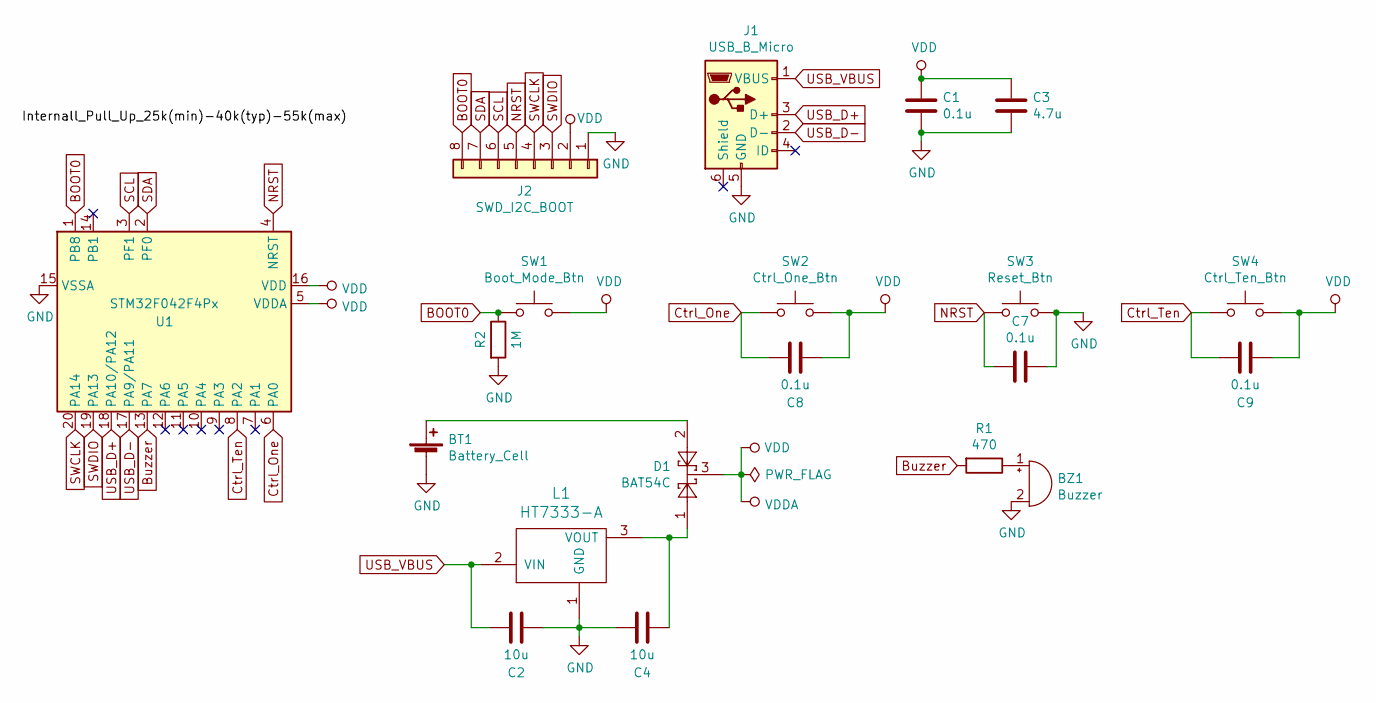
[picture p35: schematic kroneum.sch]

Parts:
BT1: Battery_Cell; BatteryHolder_LINX_BAT-HLD-012-SMT
BZ1: Buzzer; Buzzer_Murata_PKMCS0909E4000-R1
C1, C7, C8, C9: 0.1u; C_0805_2012Metric_Pad1.15x1.40mm_HandSolder
C2, C4: 10u; C_0805_2012Metric_Pad1.15x1.40mm_HandSolder
C3: 4.7u; C_0805_2012Metric_Pad1.15x1.40mm_HandSolder
D1: BAT54C; SOT-23
J1: USB_B_Micro; USB_Micro-B_Molex-105017-0001
J2: SWD_I2C_BOOT; PinSocket_1x08_P2.54mm_Vertical
L1: HT7333-A; SOT-89-3
R1: 470; R_0805_2012Metric_Pad1.15x1.40mm_HandSolder
R2: 1M; R_0805_2012Metric_Pad1.15x1.40mm_HandSolder
SW1: Boot_Mode_Btn; tl3342
SW2: Ctrl_One_Btn; tl3342
SW3: Reset_Btn; tl3342
SW4: Ctrl_Ten_Btn; tl3342
U1: STM32F042F4Px; TSSOP-20_4.4x6.5mm_P0.65mm

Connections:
BOOT0: J2.8, R2.1, SW1.1, U1.1 (PB8)
Buzzer: R1.2, U1.13 (PA7)
Ctrl_One: C8.2, SW2.1, U1.6 (PA0)
Ctrl_Ten: C9.2, SW4.1, U1.8 (PA2)
GND: BT1.2 (-), BZ1.2 (+), C1.2, C2.1, C3.2, C4.2, C7.2, J1.5 (GND), J2.1, L1.1 (GND), R2.2, SW3.2, U1.15 (VSSA)
NRST: C7.1, J2.5, SW3.1, U1.4 (NRST)
unnamed: BT1.1 (+), D1.2
unnamed: BZ1.1 (-), R1.1
unnamed: C4.1, D1.1, L1.3 (VOUT)
SCL: J2.6, U1.3 (PF1)
SDA: J2.7, U1.2 (PF0)
SWCLK: J2.4, U1.20 (PA14)
SWDIO: J2.3, U1.19 (PA13)
USB_D+: J1.3 (D+), U1.18 (PA10/PA12)
USB_D-: J1.2 (D-), U1.17 (PA9/PA11)
USB_VBUS: C2.2, J1.1 (VBUS), L1.2 (VIN)
VDD: C1.1, C3.1, C8.1, C9.1, D1.3, J2.2, SW1.2, SW2.2, SW4.2, U1.5 (VDDA), U1.16 (VDD)

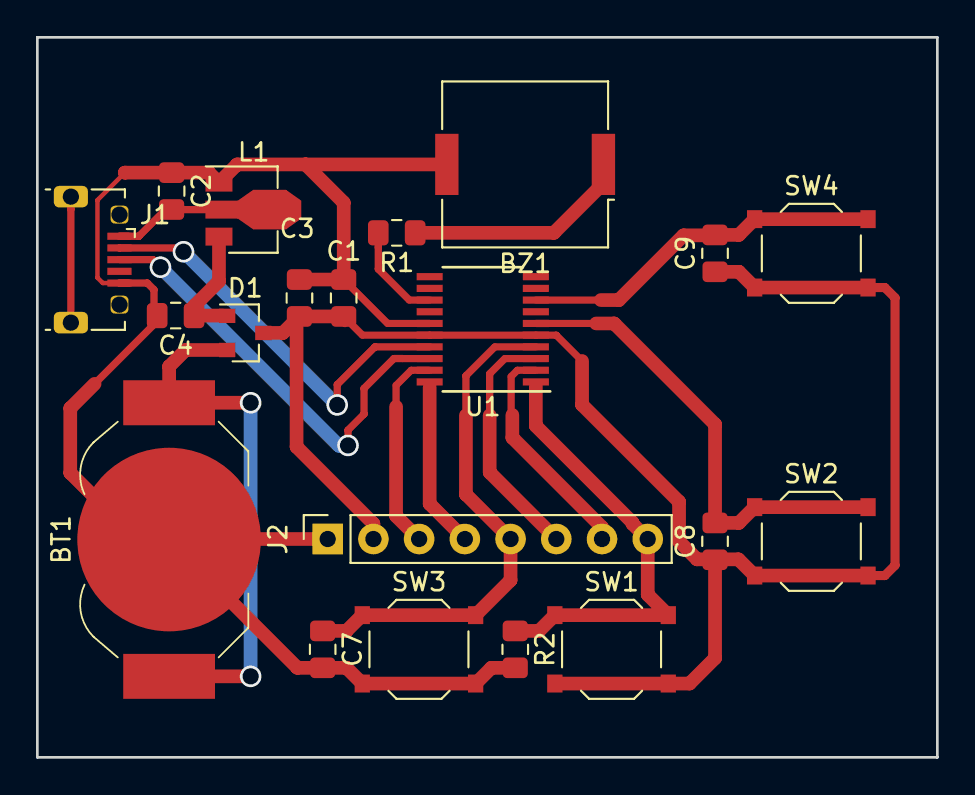
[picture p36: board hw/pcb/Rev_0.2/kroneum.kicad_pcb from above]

Board: 2 copper layers, 50.0 x 40.0 mm, 20 parts (0 on the bottom side), 17 nets.

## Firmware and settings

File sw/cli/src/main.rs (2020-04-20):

#![deny(warnings)]

#[macro_use]
extern crate log;

mod device;
mod ui;

use clap::{App, Arg, ArgMatches, SubCommand};
use device::Device;
use kroneum_api::flash::storage_slot::StorageSlot;
use std::time::Duration;

fn process_command(matches: ArgMatches) -> Result<(), String> {
    match matches.subcommand() {
        ("beep", Some(matches)) => {
            Device::create()?.beeper_beep(
                matches
                    .value_of("NUMBER")
                    .ok_or_else(|| "<NUMBER> argument is not provided.".to_string())
                    .and_then(|number_str| {
                        number_str.parse::<u8>().or_else(|err| {
                            Err(format!("Failed to parse <NUMBER> argument: {:?}", err))
                        })
                    })?,
            )?;
        }
        ("info", _) => {
            let device = Device::create()?;
            println!("Kroneum ({})", device.get_info(),);
        }
        ("alarm", Some(matches)) => match matches.value_of("ACTION").unwrap_or_else(|| "get") {
            "set" => {
                Device::create()?.set_alarm(
                    matches
                        .value_of("ALARM")
                        .ok_or_else(|| "<ALARM> argument is not provided.".to_string())
                        .and_then(|alarm_str| {
                            alarm_str.parse::<humantime::Duration>().or_else(|err| {
                                Err(format!("Failed to parse <ALARM> argument: {:?}", err))
                            })
                        })
                        .map(|alarm_human| {
                            let duration: Duration = alarm_human.into();
                            duration
                        })?,
                )?;
            }
            "get" => {
                println!(
                    "Current alarm is set to: {}",
                    humantime::Duration::from(Device::create()?.get_alarm()?)
                );
            }
            _ => {}
        },
        ("flash", Some(matches)) => match matches.value_of("ACTION").unwrap() {
            "erase" => {
                Device::create()?.erase_flash()?;
                println!("Flash is erased");
            }
            operation => {
                let device = Device::create()?;
                let slot = StorageSlot::Custom(
                    matches
                        .value_of("SLOT")
                        .ok_or_else(|| "<SLOT> argument is not provided.".to_string())
                        .and_then(|slot_str| {
                            u8::from_str_radix(&slot_str[2..], 16).or_else(|err| {
                                Err(format!("Failed to parse <SLOT> argument: {:?}", err))
                            })
                        })?,
                );

                match operation {
                    "write" => {
                        let value = matches
                            .value_of("VALUE")
                            .ok_or_else(|| "<VALUE> argument is not provided.".to_string())
                            .and_then(|value_str| {
                                u8::from_str_radix(value_str, 10).or_else(|err| {
                                    Err(format!("Failed to parse <VALUE> argument: {:?}", err))
                                })
                            })?;

                        device.write_flash(slot, value)?;

                        println!("Value {} is written to memory.", value);
                    }
                    "read" => println!("Value read from memory: {}", device.read_flash(slot)?),
                    _ => {}
                }

                device.read_flash(slot)?;
            }
        },

        ("reset", _) => {
            println!("Device is being reset...");
            Device::create()?.system_reset()?
        }

        ("ui", Some(matches)) => ui::run_server(
            matches
                .value_of("PORT")
                .ok_or_else(|| "<PORT> argument is not provided.".to_string())
                .and_then(|number_str| {
                    number_str
                        .parse::<u16>()
                        .or_else(|err| Err(format!("Failed to parse <PORT> argument: {:?}", err)))
                })?,
        )?,
        _ => return Err("Unknown sub-command!".to_string()),
    };

    Ok(())
}

fn main() -> Result<(), String> {
    env_logger::init();

    let matches = App::new("Kroneum CLI")
        .version("0.1.0")
        .author("Aleh Zasypkin <aleh.zasypkin@gmail.com>")
        .about("Allows to manage and configure Kroneum devices.")
        .subcommand(
            SubCommand::with_name("beep")
                .about("Makes Kroneum beep <NUMBER> of times")
                .arg(
                    Arg::with_name("NUMBER")
                        .short("n")
                        .long("number")
                        .takes_value(true)
                        .default_value("1")
                        .help("Defines number of beeps"),
                ),
        )
        .subcommand(SubCommand::with_name("info").about("Prints information about Kroneum device"))
        .subcommand(
            SubCommand::with_name("alarm")
                .about("Manages Kroneum alarm")
                .arg(
                    Arg::with_name("ACTION")
                        .index(1)
                        .possible_values(["set", "get"].as_ref())
                        .help("Sets or gets Kroneum alarm"),
                )
                .arg(
                    Arg::with_name("ALARM")
                        .index(2)
                        .default_value("5s")
                        .required_if("ACTION", "set")
                        .help("Alarm to set in the hh:mm:ss form."),
                ),
        )
        .subcommand(
            SubCommand::with_name("flash")
                .about("Manages Kroneum flash memory")
                .arg(
                    Arg::with_name("ACTION")
                        .index(1)
                        .required(true)
                        .possible_values(["read", "write", "erase"].as_ref())
                        .help("Reads from, writes to or erases Kroneum flash memory"),
                )
                .arg(
                    Arg::with_name("SLOT")
                        .index(2)
                        .required_ifs(&[("ACTION", "read"), ("ACTION", "write")])
                        .possible_values(&["1", "2", "3", "4"])
                        .help("Address of the memory slot."),
                )
                .arg(
                    Arg::with_name("VALUE")
                        .index(3)
                        .required_if("ACTION", "write")
                        .help("Value to write to a memory slot. Value must be an unsigned byte."),
                ),
        )
        .subcommand(SubCommand::with_name("reset").about("Resets Kroneum device"))
        .subcommand(
            SubCommand::with_name("ui")
                .about("Starts a web server with UI to manage Kroneum")
                .arg(
                    Arg::with_name("PORT")
                        .short("p")
                        .long("port")
                        .takes_value(true)
                        .default_value("8080")
                        .help("Defines a TCP port to listen on"),
                ),
        )
        .get_matches();

    process_command(matches)
}

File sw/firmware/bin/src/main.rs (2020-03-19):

//#![deny(warnings)]
#![allow(clippy::missing_safety_doc)]
#![no_main]
#![no_std]

extern crate panic_reset;

mod adc;
mod beeper;
mod buttons;
mod flash;
mod radio;
mod rtc;
mod system;
mod systick;
mod timer;
mod usb;

use crate::hal::{stm32, stm32::interrupt};
use crate::{system::SystemHardwareImpl, systick::SystickHardwareImpl};
use core::cell::RefCell;
use cortex_m::interrupt::{CriticalSection, Mutex};
use cortex_m_rt::{entry, exception, ExceptionFrame};
use kroneum_api::{system::System, systick::SysTick};
use stm32f0xx_hal as hal;

static SYSTEM: Mutex<RefCell<Option<System<SystemHardwareImpl, SystickHardwareImpl>>>> =
    Mutex::new(RefCell::new(None));
fn get_system<F>(f: F)
where
    F: FnOnce(&mut System<SystemHardwareImpl, SystickHardwareImpl>, &CriticalSection),
{
    cortex_m::interrupt::free(|cs| {
        if let Some(system) = SYSTEM.borrow(cs).borrow_mut().as_mut() {
            f(system, cs);
        }
    });
}

#[entry]
fn main() -> ! {
    if let (Some(device), Some(core)) = (stm32::Peripherals::take(), cortex_m::Peripherals::take())
    {
        cortex_m::interrupt::free(|cs| {
            *SYSTEM.borrow(cs).borrow_mut() = Some(System::run(
                system::SystemHardwareImpl::init(device, core.SCB, core.NVIC, &cs),
                SysTick::new(SystickHardwareImpl::new(core.SYST)),
            ));
        });
    }

    loop {
        get_system(|system, _cs| system.sleep());
        cortex_m::asm::wfi();
    }
}

#[interrupt]
fn EXTI2_3() {
    get_system(|system, _cs| system.handle_button_press());
}

#[interrupt]
fn EXTI0_1() {
    get_system(|system, _cs| system.handle_button_press());
}

#[interrupt]
fn RTC() {
    get_system(|system, _cs| system.handle_alarm());
}

#[interrupt]
fn USB() {
    get_system(|system, cs| system.handle_usb_packet(cs));
}

#[interrupt]
fn TIM2() {
    get_system(|system, _cs| system.handle_timer());
}

#[exception]
fn DefaultHandler(irqn: i16) {
    panic!("unhandled exception (IRQn={})", irqn);
}

#[exception]
fn HardFault(_ef: &ExceptionFrame) -> ! {
    panic!("hard fault (PC={})", _ef.pc);
}

#[exception]
fn SysTick() {
    get_system(|system, _cs| system.handle_systick());
}

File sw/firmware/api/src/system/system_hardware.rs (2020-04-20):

use adc::ADCHardware;
use beeper::PWMBeeperHardware;
use buttons::ButtonsHardware;
use flash::FlashHardware;
use radio::RadioHardware;
use rtc::RTCHardware;
use timer::TimerHardware;
use usb::USBHardware;

/// Describes the SystemControl hardware management interface.
pub trait SystemHardware:
    ADCHardware
    + ButtonsHardware
    + FlashHardware
    + PWMBeeperHardware
    + RTCHardware
    + RadioHardware
    + USBHardware
    + TimerHardware
{
    /// Forces system to enter StandBy mode.
    fn enter_deep_sleep(&mut self);

    /// Forces system to exit StandBy mode.
    fn exit_deep_sleep(&mut self);

    /// Performs system software reset.
    fn reset(&mut self);

    /// Returns a 12-byte unique device ID.
    fn device_id(&self) -> &'static [u8; 12];

    /// Returns a string with a hex-encoded unique device ID.
    fn device_id_hex(&self) -> &'static str;

    /// Returns the Flash memory size of the device in Kilobytes.
    fn flash_size_kb(&self) -> u16;
}

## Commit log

2018-12-25 Create schematics v1.
    [kroneum.kicad_pcb, kroneum.sch]
2018-12-27 Initial firmware.
    [kroneum.sch]
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2019-01-08 stm32f0x2: add missing `pa11_pa12_rmp` register and rename `usbrst` to `usben`.
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2019-01-10 cli: properly release interface and attach kernel driver if it was detached.
2019-01-11 cli: incorporated clippy fix suggestion.
    [main.rs]
2019-01-11 hw: switch `ten-1` button from PA5 to PA0 to be able to wake up device from stand-by mode.
    [kroneum.kicad_pcb, kroneum.sch]
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2019-01-12 firmware: use HSI as main clock all the time, start/stop USB clock and device on demand only.
2019-01-12 firmware: replace start/stop with more appropriate setup/teardown.
    [beeper.rs, main.rs]
2019-01-12 firmware: revive low power mode (still ~300 micro amps, needs more improvements).
2019-01-13 hw: connect x-button to PA2 instead of PA5 (to have access to wkup4).
    [kroneum.kicad_pcb, kroneum.sch]
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2019-01-13 hw: use default pull-downs for PA0 and PA2.
    [kroneum.kicad_pcb, kroneum.sch]
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2019-01-14 firmware: introduce `System` module. Fix RTC Alarm to respect seconds, minutes and hours.
    [beeper.rs, main.rs, system.rs]
2019-01-14 firmware: make beep and blink shorter.
    [beeper.rs]
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2019-01-15 hw: switch to Rev 0.2 of schematics (removed crystal).
    [kroneum.kicad_pcb, kroneum.sch]
2019-01-15 firmware: enable AIN mode for unused pins to reduce power consumption (~50 uA now).
2019-01-16 hw: use tl3342 for control and reset buttons.
    [kroneum.kicad_pcb, kroneum.sch]
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2019-01-18 hw: use momentary switch for boot mode selector.
    [kroneum.kicad_pcb, kroneum.sch]
2019-01-20 firmware: tighten member visibility.
2019-01-21 hw: provide footprint for SWD header.
    [kroneum.kicad_pcb, kroneum.sch]
2019-01-24 hw: reorganize headers on PCB.
    [kroneum.kicad_pcb, kroneum.sch]
2019-01-26 hw: more work on PCB.
    [kroneum.kicad_pcb]
2019-01-26 hw: first PCB version with all nets connected.
    [kroneum.kicad_pcb, kroneum.sch]
2019-01-26 hw: semi final PCB versions.
    [kroneum.kicad_pcb]
2019-01-26 hw: fix PCB clearance issues.
    [kroneum.kicad_pcb]
2019-01-26 hw: pcb remove redundant traces.
    [kroneum.kicad_pcb]
2019-01-26 hw: convert micro-usb PTH to mechanical NPTH. Export STEP model of the device to Autodesk Fusion 360.
    [kroneum.kicad_pcb]
2019-01-30 hw: decrease width of TSSOP20 pads, first export of Gerbers.
    [kroneum.kicad_pcb, kroneum.sch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]
2019-02-02 hw: add decoupling capacitors for the voltage regulator.
    [kroneum.kicad_pcb, kroneum.sch]
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2019-02-02 hw: make all PCB holes 0.9mm.
    [kroneum.kicad_pcb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]
2019-02-02 hw: export final PCB Gerber files.
    [kroneum-Edge.Cuts.gbr, kroneum-F.Cu.gbr]
2019-02-02 hw: prepare isolation, cutout and drilling NC files.
    [kroneum.kicad_pcb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]
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2019-02-11 firmware: fix PMA IN address for the device endpoint.
2019-02-11 cli: move USB device specific code to `device` module. Add support for `Beep`, `Info`, `GetAlarm` and `SetAlarm` commands.
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2019-02-13 cli: fix subcommand parsing logic.
    [main.rs]
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2019-02-19 cli: do not check kernel driver status if driver does not support it.
2019-02-21 hw: change naming schema for pcb revisions (no space in the name).
    [kroneum.kicad_pcb, kroneum.sch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]
2019-02-21 hw: add Rev 0.3 PCB revision (with proper battery holder and test points).
    [kroneum.kicad_pcb, kroneum.sch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]
2019-02-21 hw: finish PCB Rev 0.3
    [kroneum.kicad_pcb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]
2019-02-24 hw: generate pcb gerbers.
    [kroneum-Edge.Cuts.gbr, kroneum-F.Cu.gbr, kroneum-NPTH.drl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]
2019-02-27 hw: include enclosure CNC files and 3d model.
    [kroneum.step]
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2019-03-03 hw: adjust PCB manufacturing settings (add forgotten multidepth for cutout and increase drill and cutout depth).
2019-03-04 hw: update G-Code for the enclosure (multiple depth for adaptive, changed zero point for the cap).
2019-03-04 hw: add demo shots and include G-Code for the enclosure Rev_0.2.
    [kroneum.step]
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2019-03-08 fw: fix bug in `Time.add_hours` when the amount of hours to add exceeds 48. Add `Time` tests.
    [system.rs]
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2019-03-14 fw: migrate to `stm32f0` crate and ditch my own svd2rust generated device crate.
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2019-03-14 fw: switch to proper bit enums for the registers. Remove all `unsafe` from main.
2019-03-15 fw: fix clippy warnings.
    [beeper.rs]
2019-03-17 Revert `RTFM migration` commit as RTFM does not allow sharing of SCB to manage DEEPSLEEP mode.
    [beeper.rs, main.rs, system.rs]
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2019-03-23 cli: allow CLI to reset Kroneum device.
    [main.rs]
2019-03-23 fw: add `CommandPacket::Reset` test.
    [command_packet.rs]
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2019-03-26 fw: minor style fixes for the flash module.
    [system.rs]
2019-04-09 fw: introduce `Flash.erase_all` and move device specific memory addresses to binary crate.
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2019-04-19 Move system reset and standby mode management to SystemHardwareImpl.
    [system.rs]
2019-04-20 fw: rollback of `cortex-m` upgrade because of https://github.com/stm32-rs/stm32-rs/issues/184.
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2019-04-21 fw: allow `ButtonsHardware` to reset interrupts.
    [system.rs]
2019-04-24 fw: move `*HardwareImpl` to `new()` pattern. Fix remaining Clippy warnings.
    [beeper.rs, main.rs, system.rs]
2019-04-24 fw: fix button handling.
    [system.rs]
2019-04-27 fw: move standby mode and system reset management to a separate component.
    [main.rs, system.rs]
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2019-05-13 fw: enter into Idle mode when both button long pressed in Alarm mode. Rename `standby` to `deepsleep`.
2019-05-13 fw: properly teardown USB device to eliminite any leakage.
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2019-05-17 fw: require presses to be twice as short and melody 3 times as fast to drastically reduce dynamic power consumption.
    [beeper.rs]
2019-06-10 hw: introduce Rev 0.4 of PCB (changed LDO and its peripherals.
    [kroneum.kicad_pcb, kroneum.sch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]
2019-06-10 hw: fix DRC errors.
    [kroneum.kicad_pcb]
2019-06-11 hw: finish Rev 0.4 PCB layout.
    [kroneum.kicad_pcb]
2019-06-16 hw: improve PCB to allow USB port be outside of PCB and avoid collisions with the enclosure and USB cable.
    [kroneum.kicad_pcb]
2019-06-22 hw: add rounded corners to the pcb edge.
    [kroneum.kicad_pcb]
2019-06-23 hw: use proper 3D PCB models for the X and I buttons.
    [kroneum.kicad_pcb]
2019-06-23 hw: add G-Code/DXF files that were used for PCB milling (cutout and holes).
    [kroneum-F_Cu.dxf, kroneum.kicad_pcb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]
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2019-09-01 pcb: add a rev 0.5 with just a few tweaks for pcb manufacturing house.
    [kroneum-F_Cu.dxf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]
2019-09-08 [pcb] update SDW/SCL/SWCLK/SWDIO labels.
    [kroneum.kicad_pcb]
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2019-09-15 [hw] pcb rev 0.6: expose GND and VCC on tha back PCB side, give more meaningful names on silk screen.
    [kroneum.kicad_pcb, kroneum.sch]
2019-09-26 [pcb] introduce PCB rev 0.6 (reduced size to 30mmx30mm, exposed all unused pads, moved batter to the back layer)
    [kroneum-silkscreen-logo.dxf, kroneum.kicad_pcb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]
2019-09-28 [pcb] include solder mask into manufacturing bundle.
    [kroneum.kicad_pcb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]
2019-09-29 [pcb] add Octopart BOM.
    [kroneum_bom.csv]
2019-10-16 [fw] switch buzzer output from PA7 to PB1 according to PCB Rev 0.6 to make PA7 available for SPI and I2S.
    [beeper.rs, system.rs]
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2019-11-26 [fw] improve reset melody.
    [beeper.rs]
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2019-12-23 [cli] integrate eslint and prettier for the Web UI project. Merge `get_manufacturer` and `get_identifier` of Device struct.
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2020-01-02 [cli] introduce WebAudio player to check melody before sending it to the device.
2020-01-05 [fw] switch to `panic-reset` to drastically reduce firmware size.
    [main.rs]
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2020-04-10 [fw] do not respond with error if unrecognized command is received.
    [system.rs]
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
